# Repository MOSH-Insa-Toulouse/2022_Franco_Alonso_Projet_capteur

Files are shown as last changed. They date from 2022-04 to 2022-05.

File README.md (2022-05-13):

# 2022_Franco_Alonso_Projet_capteur

Ce repository Git contient les ressources nécessaire pour le projet 2022 qui s'inscrit dans l'UF *"Du capteur au banc de Test"* de l'INSA de Toulouse, 4ème année de Génie Physique.

---
## Sommaire

- [2022_Franco_Alonso_Projet_capteur](#2022_franco_alonso_projet_capteur)
  - [Sommaire](#sommaire)
  - [1) Livrables](#1-livrables)
  - [2) Description](#2-description)
  - [3) Shield PCB](#3-shield-pcb)
  - [4) Arduino](#4-arduino)
  - [5) Application Android APK](#5-application-android-apk)
    - [5.1) MIT App inventor](#51-mit-app-inventor)
    - [5.2) Notre application](#52-notre-application)
  - [6) Banc de test](#6-banc-de-test)
    - [6.1) Rayon de courbure](#61-rayon-de-courbure)
    - [6.2) Répétabilité](#62-répétabilité)
  - [7) Datasheet](#7-datasheet)
  - [8) Information sur les auteurs](#8-information-sur-les-auteurs)

---
## 1) Livrables

- Shield PCB réalisé avec KiCad
- Code Arduino permettant la mesure de la resistance et de la tension du capteur, ainsi que le contrôle d'un module Bluetooth, d'un écran OLED et d'un encodeur rotatoire
- Application android APK réalisée avec MIT APP INVENTOR
- Protocole et code Arduino du Banc de test
- Datasheet du capteur de déformation

---
## 2) Description

Dans le cadre de l'UF MOSH, nous avons conçu un capteur résistif composé de matériaux peu chers : un simple papier et un crayon suffisent à créer ce capteur.

Ici, le phénomène physique observé est l'effet tunnel. En effet, il existe un lien entre la conduction des électrons et la distance interatomique du réseau percolet. En faisant varier la distance séparant les particules du réseau (en pliant une feuille de papier sur laquelle on aura déposé du graphite par exemple), la conductivité du graphite varie, la résistivité varie également, et donc, la résistance variera aussi en fonction des dimensions du capteur. C'est cette propriété que l'on va exploiter afin de créer notre capteur résistif.  

Nous avons également implémenté  un shield sur notre chaine de mesures. Ce dernier a été conçu a l'aide du logiciel KICAD et aura un rôle de conditionneur du signal. Le shield est composé d'un amplificateur transimpédance, d'un module Bluetooth, d'un écran OLED, d'un encodeur rotatoire ainsi que d'une entrée analogique pour le capteur résistif.  

Pour finir, nous avons effectué l'ensemble des tests du circuit sur le logiciel LTSpice (voir [_Rapport LTSpice_](https://github.com/MOSH-Insa-Toulouse/2022_Franco_Alonso_Projet_capteur/blob/8504636d878c9423babecade3b70e7a892836c6b/Rapport_LTSpice.pdf)).  

Nous avons ensuite imprimé notre circuit PCB après validation de l'équipe pédagogique.  

Puis, nous avons utilisé une carte Arduino pour la lecture des mesures et la création des fonctions relatives à l'écran OLED, au module Bluetooth ainsi qu'a l'encodeur rotatoire.  

Ensuite, avec le site MIT App Inventor, nous avons développé une application Android qui a pour but de recevoir des données via Bluetooth.  

Et enfin, nous avons réalisé notre propre banc de test : nous avons effectué un test de rayon de courbure et un test de répétabilité avec deux types de crayons (B, HB).  

---
## 3) Shield PCB

Sur le logiciel KICAD nous avons créé des modèles pour l'amplificateur transimpédance, le module Bluetooth, l'écran OLED et l'encodeur rotatoire. Nous avons ensuite créé ou assigné des empreintes à chaque composante du circuit électronique (amplificateur, Bluetooth, OLED, encodeur rotatoire mais aussi résitances et capacités). Puis, nous avons tracé le chevelu du PCB et enfin nous avons modélisé notre PCB en 3D pour vérifier qu'aucun élément ne se superpose et qu'il n'y aura pas de problème lors de la réalisation du PCB.  

Schéma du circuit électrique sur LTSpice:  
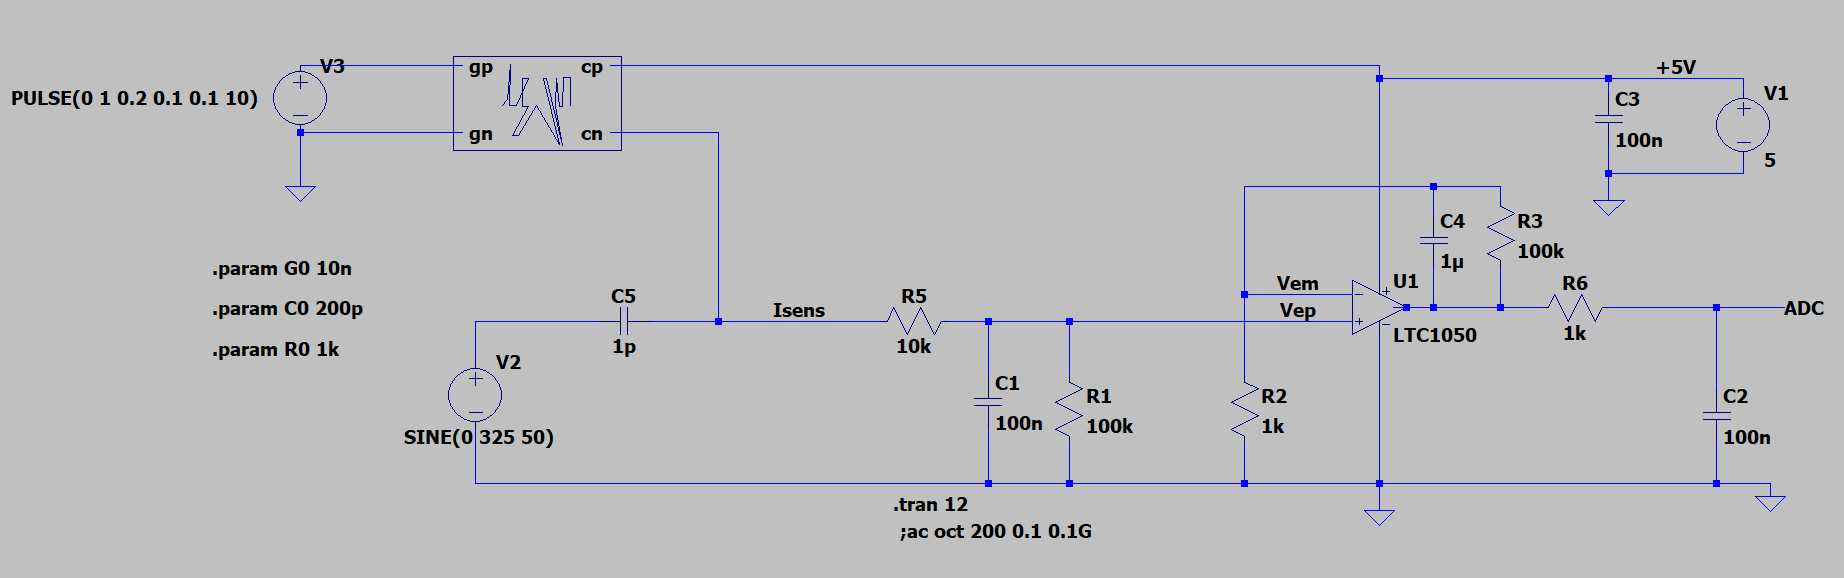
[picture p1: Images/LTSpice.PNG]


Schématique de l'amplificateur opérationel LTC1050:  
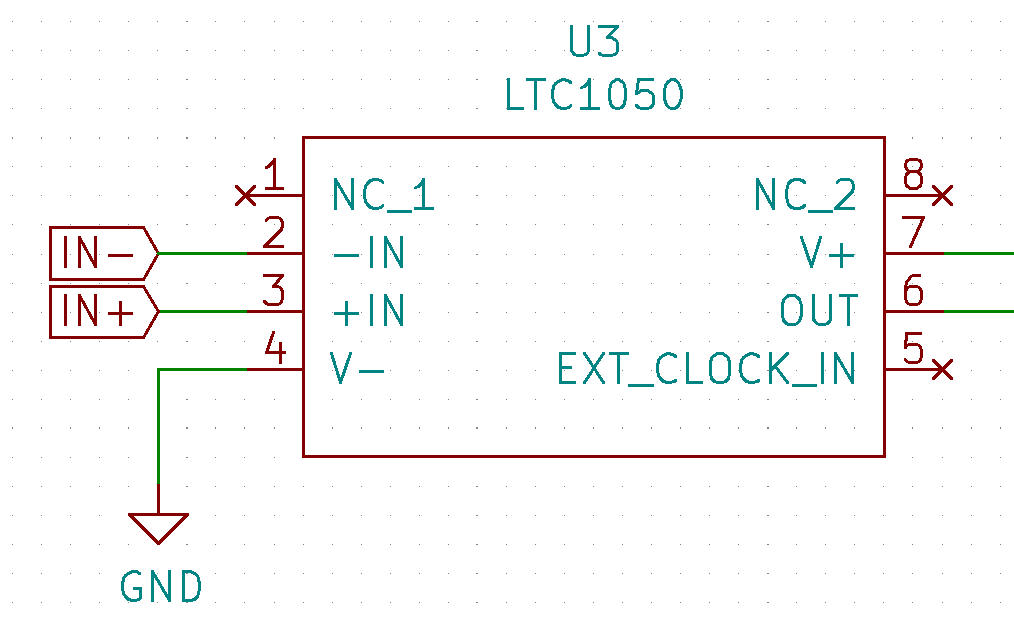
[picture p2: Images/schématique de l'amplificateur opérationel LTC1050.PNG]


Schématique du module Bluetooth HC-05:  
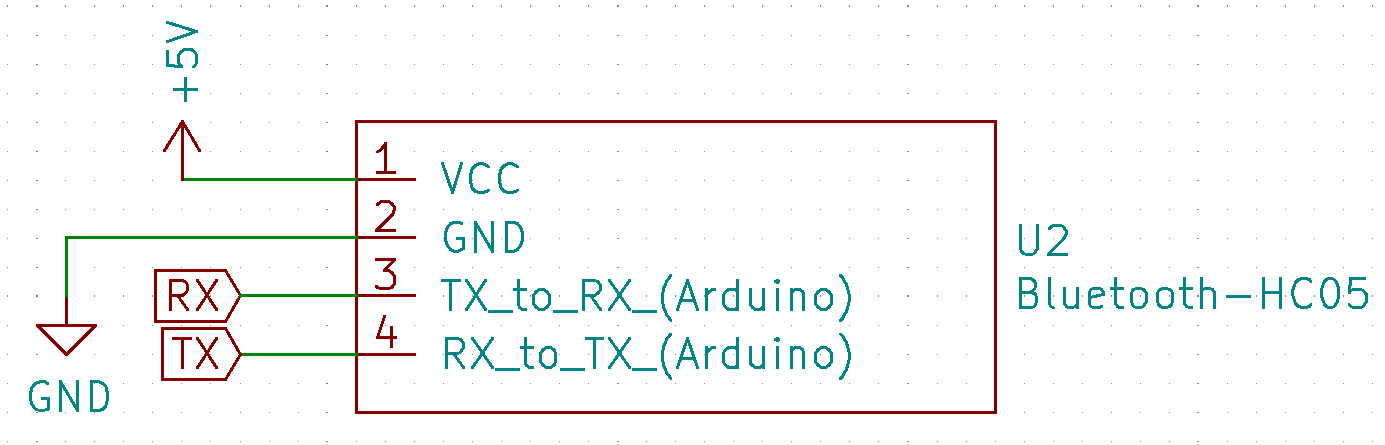
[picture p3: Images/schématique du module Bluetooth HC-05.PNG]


Schématique de l'écran OLED:  
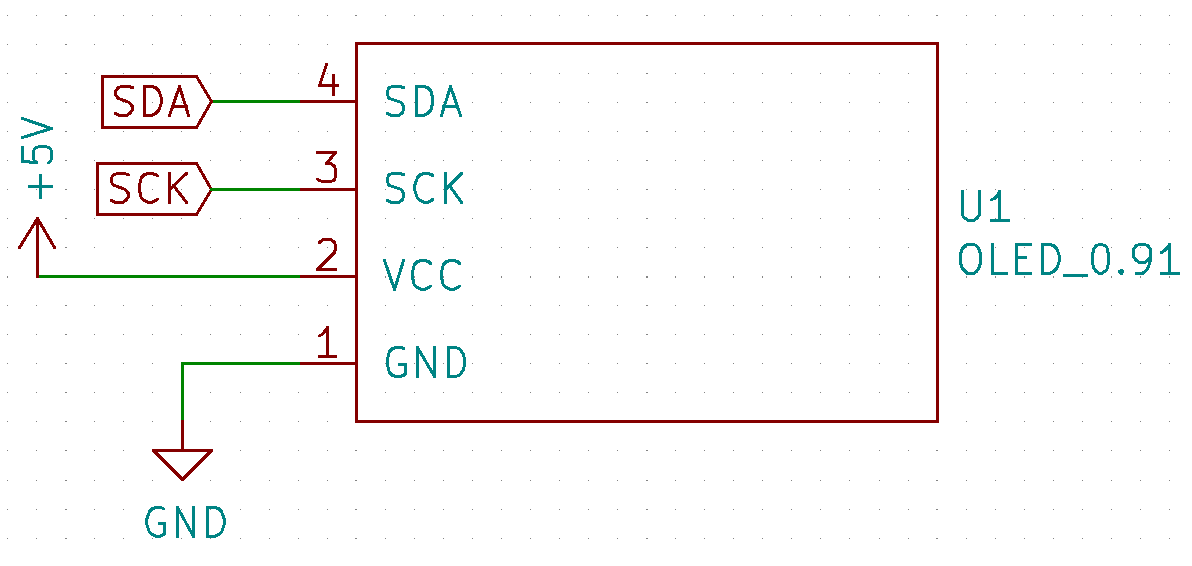
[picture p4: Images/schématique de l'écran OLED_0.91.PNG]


Schématique de l'encodeur rotatoire KY-040:  
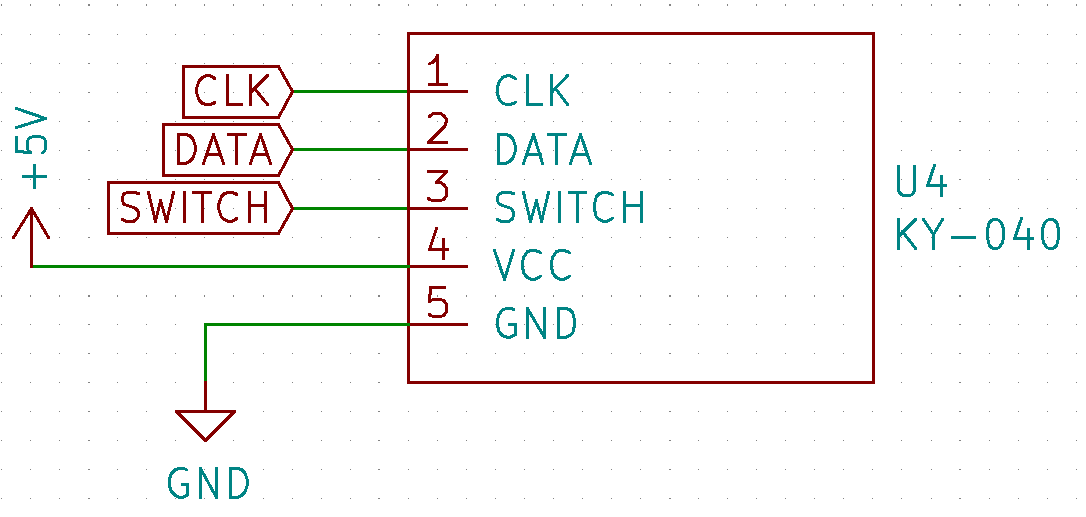
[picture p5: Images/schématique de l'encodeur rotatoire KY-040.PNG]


Schématique des pins de la carte Arduino:  
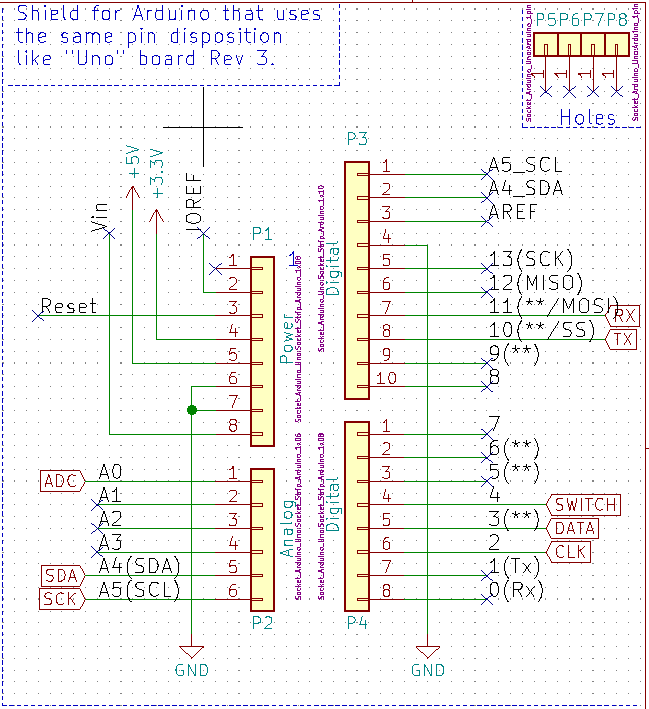
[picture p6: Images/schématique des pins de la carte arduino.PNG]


Schématique du circuit amplificateur transimpédance:  
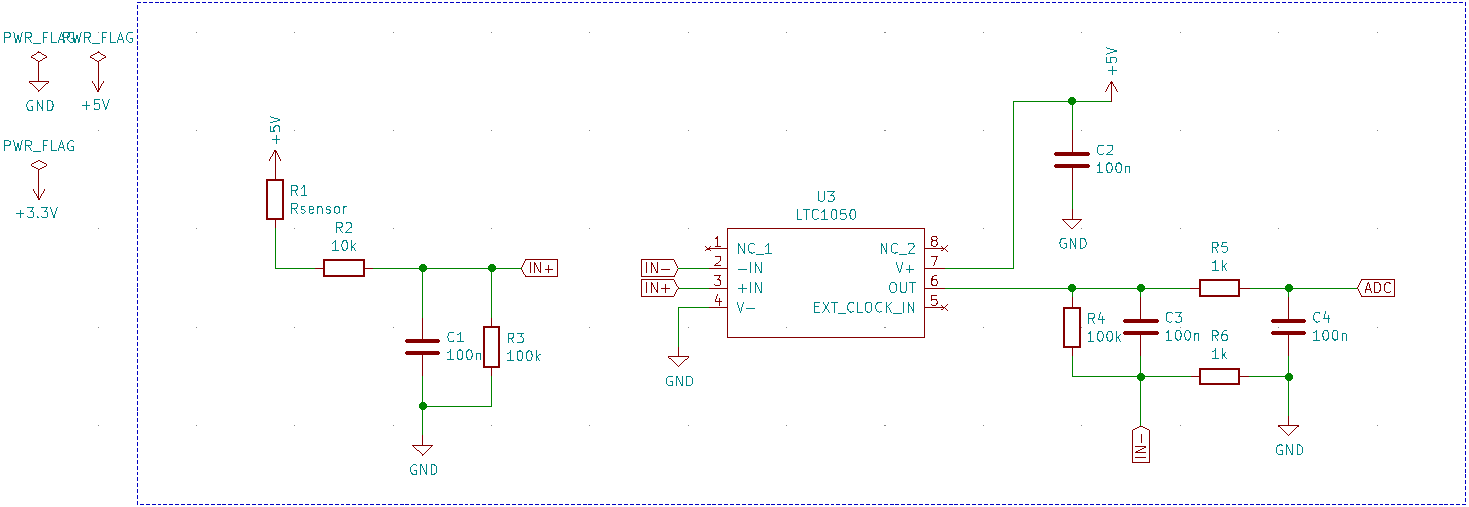
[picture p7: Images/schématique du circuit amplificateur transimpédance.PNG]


Empreinte de l'amplificateur opérationel LTC1050:  
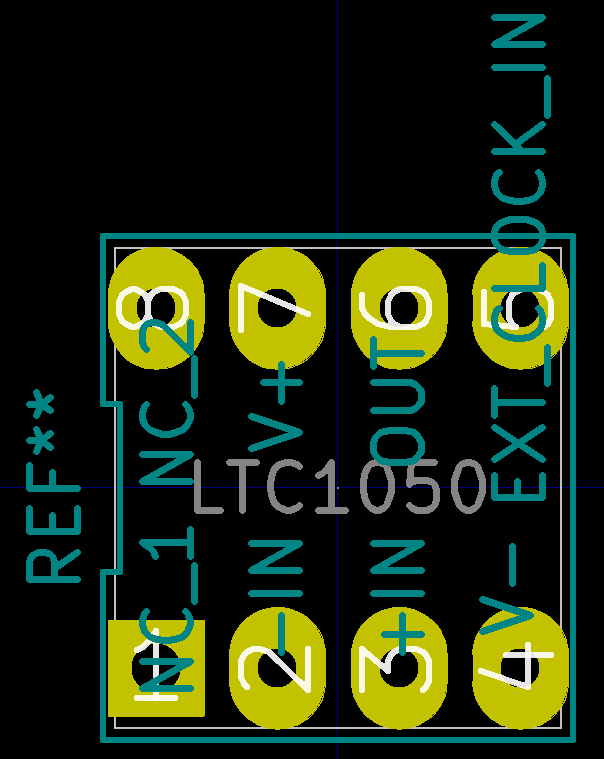
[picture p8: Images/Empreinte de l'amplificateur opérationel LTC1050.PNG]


Empreinte du module Bluetooth HC-05:  
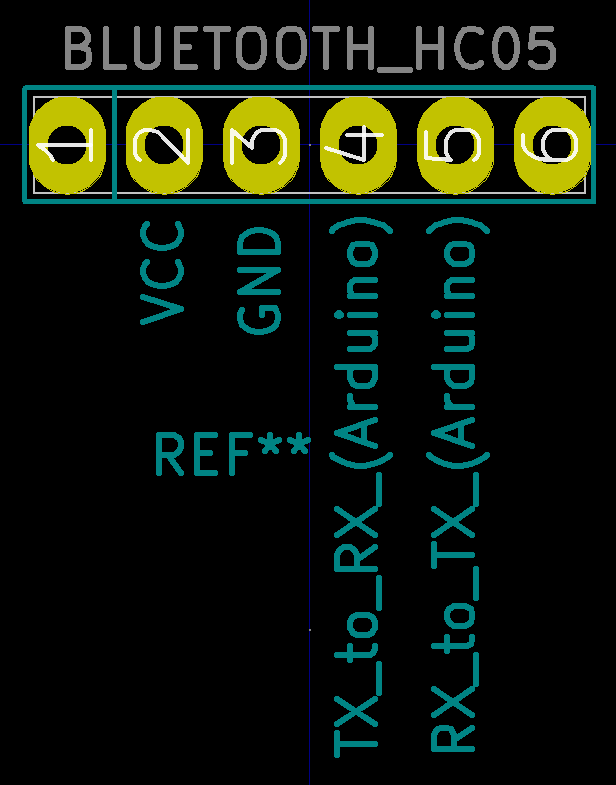
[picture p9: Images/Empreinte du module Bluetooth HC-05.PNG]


Empreinte de l'écran OLED:  
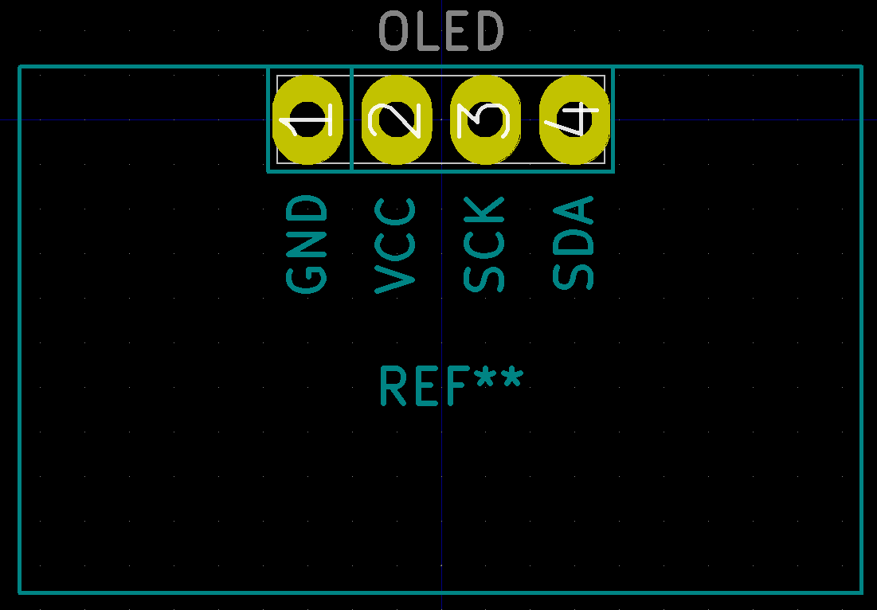
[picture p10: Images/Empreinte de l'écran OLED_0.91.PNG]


Empreinte de l'encodeur rotatoir KY-040:  
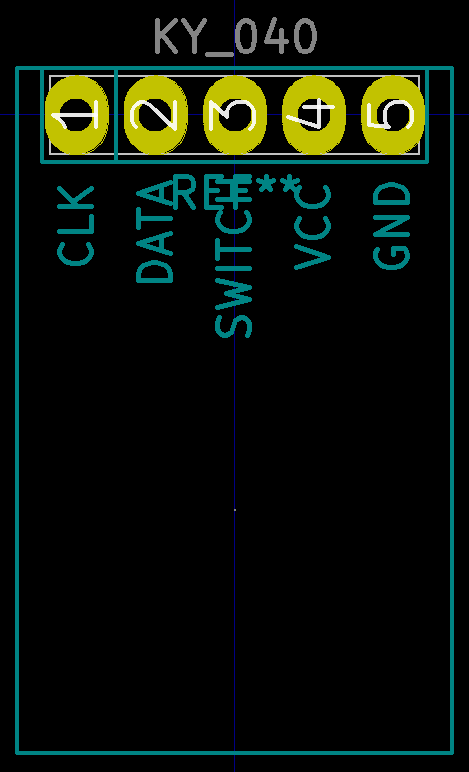
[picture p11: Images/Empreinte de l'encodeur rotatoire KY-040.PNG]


Empreinte du PCB en entier:  
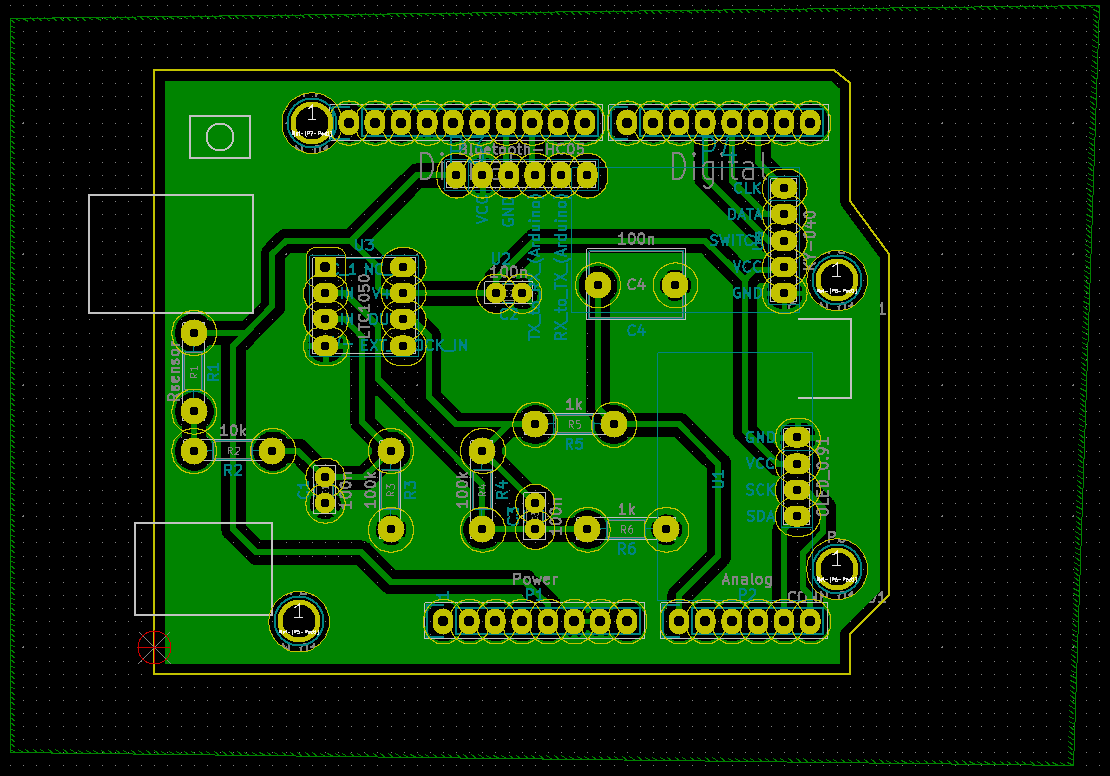
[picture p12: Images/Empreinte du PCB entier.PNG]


Modélisation 3D du PCB:  
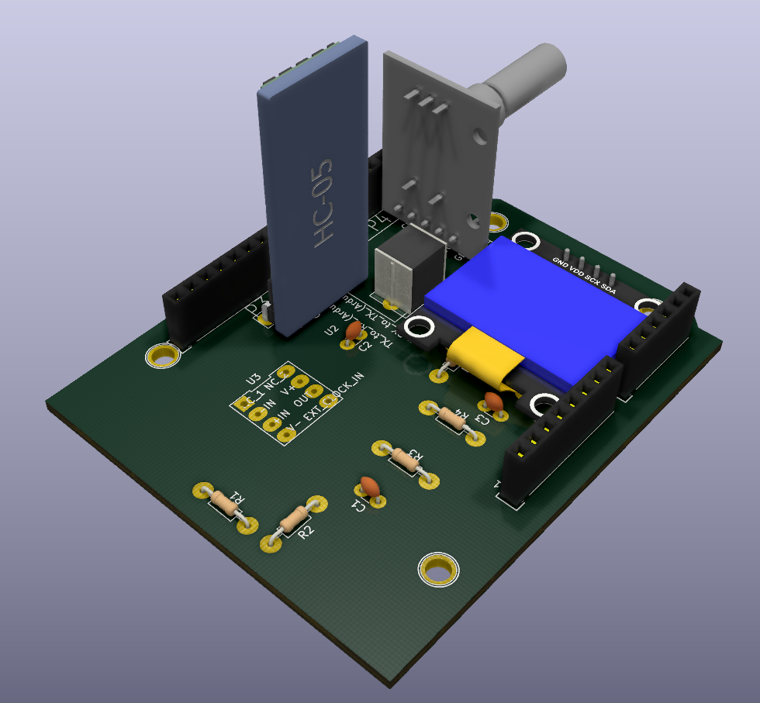
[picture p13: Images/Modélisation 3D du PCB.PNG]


---
## 4) Arduino

Voici notre code Arduino qui permet de :

- mesurer la tension en sortie du circuit transimpédance
- calculer la résistance correspondante du capteur grâce à la tension mesurée (fonction de transfert)
- visualiser ces valeurs (tension et résistance) dans le moniteur série
- afficher ces deux valeurs (tension et résistance) sur l'écran OLED
- envoyer les valeurs de résistance par Bluetooth à l'application APK
- utiliser un encodeur rotatoire pour choisir d'afficher sur l'écran OLED et d'envoyer par Bluetooth les valeurs de résistance en Ω, kΩ ou MΩ  

```
// Pour le Bluetooth
#include <SoftwareSerial.h>
#include <Arduino.h>
#include <string.h>
#define rxPin 11 //Broche 11 en tant que RX, à raccorder sur TX du HC-05
#define txPin 10 //Broche 10 en tant que TX, à raccorder sur RX du HC-05
#define baudrate 9600
#define encoder0PinA  2  //CLK Output A Do not use other pin for clock as we are using interrupt
#define encoder0PinB  3  //DT Output B
#define Switch 5 // Switch connection if available
int value;
int rotation;
int RotPosition = 0;
boolean LeftRight;
float Rs2=0;
volatile unsigned int encoder0Pos = 0;
SoftwareSerial mySerial(rxPin ,txPin); //Définition du software serial

float Vadc;

// Pour le OLED
#include <Adafruit_SSD1306.h>

#define nombreDePixelsEnLargeur 128         // Taille de l'écran OLED, en pixel, au niveau de sa largeur
#define nombreDePixelsEnHauteur 64          // Taille de l'écran OLED, en pixel, au niveau de sa hauteur
#define brocheResetOLED         -1          // Reset de l'OLED partagé avec l'Arduino (d'où la valeur à -1, et non un numéro de pin)
#define adresseI2CecranOLED     0x3C        // Adresse de "mon" écran OLED sur le bus i2c (généralement égal à 0x3C ou 0x3D)

Adafruit_SSD1306 ecranOLED(nombreDePixelsEnLargeur, nombreDePixelsEnHauteur, &Wire, brocheResetOLED);

/////////////////////////////////////////////////////////////////////////////////////////////////////////////////////////////////////////////////////////////////////////

void Affichage_OLED(float Rs, float Vadc){ 
  byte tailleDeCaractere=2;
  byte numeroDeLigne=1;
  boolean bCouleurInverse = false;
  ecranOLED.clearDisplay();                                   // Effaçage de l'intégralité du buffer
  ecranOLED.setTextSize(tailleDeCaractere);                   // Taille des caractères (1:1, puis 2:1, puis 3:1)
  ecranOLED.setCursor(0, 0);                                  // Déplacement du curseur en position (0,0), c'est à dire dans l'angle supérieur gauche
  ecranOLED.setTextColor(SSD1306_WHITE);                  // Affichage du texte en "blanc" (avec la couleur principale, en fait, car l'écran monochrome peut être coloré)
  ecranOLED.print("V= ");
  ecranOLED.print(Vadc);
  ecranOLED.println(" V");
  ecranOLED.print("R= ");
  ecranOLED.print(Rs);
  bCouleurInverse = !bCouleurInverse;
  ecranOLED.display();                            // Transfert le buffer à l'écran

  // ***********************************************************************
  // Affichage de 8 lignes à couleurs alternées, dans chaque écran successif
  // ***********************************************************************
  
  /*if(bCouleurInverse)
    ecranOLED.setTextColor(SSD1306_BLACK, SSD1306_WHITE);   // Couleur du texte, et couleur du fond
  else
    
  delay(500);*/
}

/////////////////////////////////////////////////////////////////////////////////////////////////////////////////////////////////////////////////////////////////////////

double Rs;
int Vcc=5;
int R1=100000;
int R3=100000;
int R5=10000;
int R2=1000;

void Bluetooth_write(double Rs){
  double Res = Rs;
  mySerial.println(Res);
  delay(500);
}

/////////////////////////////////////////////////////////////////////////////////////////////////////////////////////////////////////////////////////////////////////////

void mesure(){
  // read the input on analog pin 0:
  double  sensorValue = analogRead(A0);         //on divise par 4 pour être sur une plage de 256 et non une plage de 1024 car l'analogRead donne une valeur entre 0 et 1023
  
  // Convert the analog reading (which goes from 0 - 1023) to a voltage (0 - 5V):
  Vadc = sensorValue * (Vcc / 1023.0);
 
  Rs = ((1+R3/R2)*R1*(1023/Vadc))-R1-R5;
  //Serial.println(Vadc); 
}

// on voit sur le moniteur que Rs varie entre 35000 et 15M environ

/////////////////////////////////////////////////////////////////////////////////////////////////////////////////////////////////////////////////////////////////////////

void setup() {
  Serial.begin(9600);
  pinMode(rxPin,INPUT);
  pinMode(txPin,OUTPUT);
  mySerial.begin(9600);
  ecranOLED.begin(SSD1306_SWITCHCAPVCC, adresseI2CecranOLED);
  pinMode(encoder0PinA, INPUT); 
  digitalWrite(encoder0PinA, HIGH);       // turn on pullup resistor
  pinMode(encoder0PinB, INPUT); 
  digitalWrite(encoder0PinB, HIGH);       // turn on pullup resistor
  rotation = digitalRead(encoder0PinA); 
}

void loop() {
 value = digitalRead(encoder0PinA);
     if (value != rotation){ // we use the DT pin to find out which way we are turning.
     if (digitalRead(encoder0PinB) != value) {  // Clockwise
       RotPosition ++; 
       if (RotPosition==3){
        RotPosition=0;
       }
     } else { //Counterclockwise
       RotPosition--;
       if (RotPosition==-3){
        RotPosition=0;
       }
     }
     rotation = value;
     }
    mesure();
      if (RotPosition==-1){
        //mesure();
        Rs=Rs/1000;
        Bluetooth_write(Rs);  
        Affichage_OLED(Rs, Vadc);
        //Serial.println(Rs);
        ecranOLED.println(" k");
        ecranOLED.display();
     }
      else if (RotPosition==-2){
        //mesure();
        //Serial.println(Rs/1000000);
        Bluetooth_write(Rs/1000000);
        Affichage_OLED(Rs/1000000, Vadc);
        ecranOLED.println(" M");
        ecranOLED.display();
     }
     else if (RotPosition==0){
        //Serial.println(Rs);
      Bluetooth_write(Rs);
      Affichage_OLED(Rs, Vadc); 
     }
      else if (RotPosition==1){
        //mesure();
        Rs=Rs/1000;
        Bluetooth_write(Rs);  
        Affichage_OLED(Rs, Vadc);
        //Serial.println(Rs);
        ecranOLED.println(" k");
        ecranOLED.display();
     }
      else if (RotPosition==2){
        //mesure();
       // Serial.println(Rs/1000000);
        Bluetooth_write(Rs/1000000);
        Affichage_OLED(Rs/1000000, Vadc);
        ecranOLED.println(" M");
        ecranOLED.display();
     }
     else{
      //mesure();
      //Serial.println(Rs);
      Bluetooth_write(Rs);
      Affichage_OLED(Rs, Vadc);  
     }
     //Serial.print("Encoder RotPosition: ");
     //Serial.println(RotPosition);
     
     Serial.println(Rs);
     //Serial.println(Vadc);
     // this will print in the serial monitor.  
}
```

---
## 5) Application Android APK

L'application android développée sur MIT App Inventor sert à:

- Récupérer la valeur de la résistance du capteur graphite (calculée par le code Arduino à partir de la tension mesurée)
- Afficher cette valeur de résistance
- Tracer un graphique qui décrit l'évolution de la résistance du capteur en fonction du temps

### 5.1) MIT App inventor

Le site internet de création d'application [_MIT App Inventor_](https://appinventor.mit.edu/)

### 5.2) Notre application

Interface de l'application sur un smartphone :  
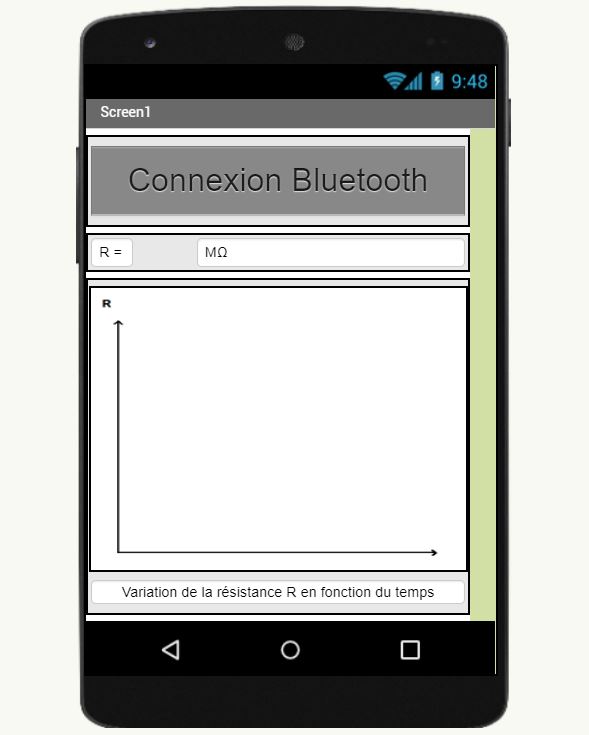
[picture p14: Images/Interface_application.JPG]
  

Schéma en block du code de l'application :  
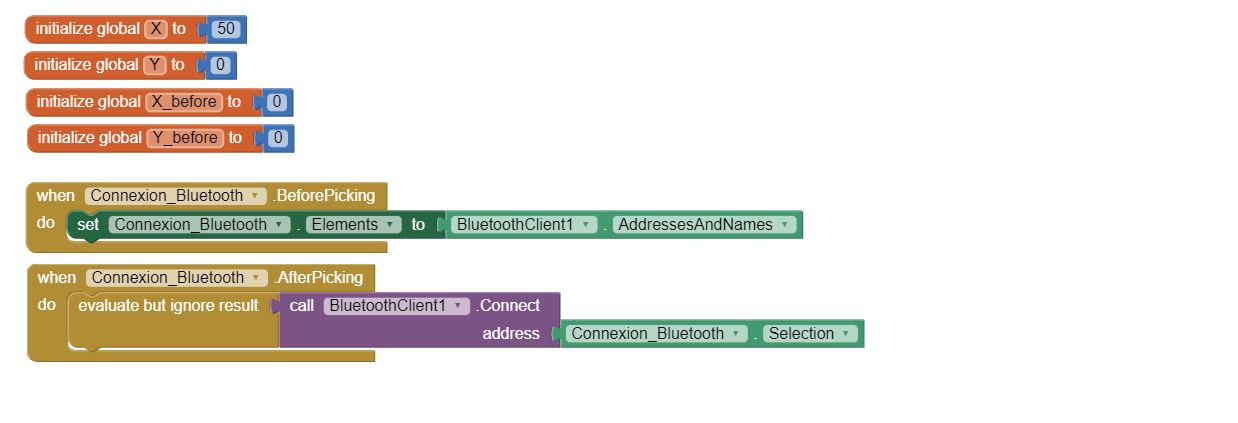
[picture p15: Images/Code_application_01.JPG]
  
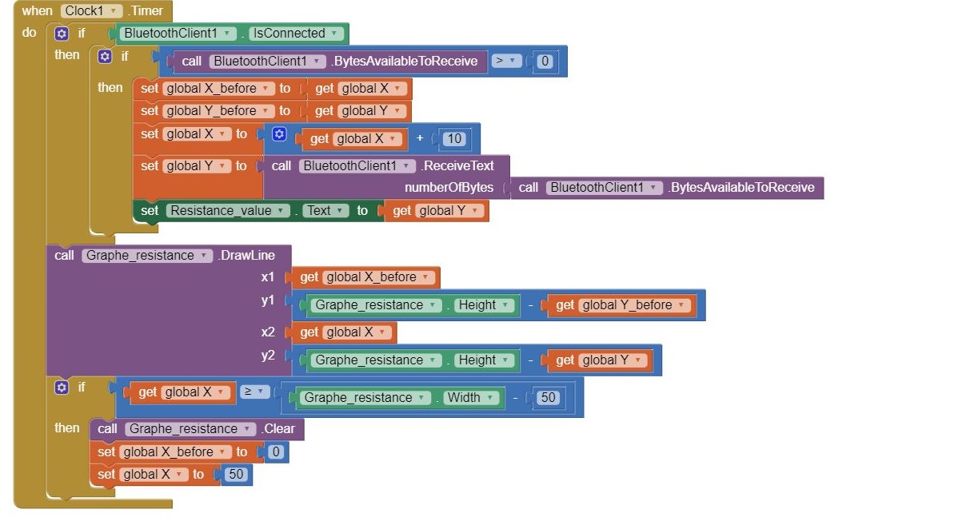
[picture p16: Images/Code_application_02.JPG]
  

Toutefois, notre application est perfectible. Il lui arrive d'avoir des erreurs obligeant l'application à se fermer, notamment lorsque le smartphone reçoit des valeurs infinies.  

---
## 6) Banc de test

### 6.1) Rayon de courbure

Nous avons effectué différents tests pour étudier l'influence du rayon de courbure sur la résistance de notre capteur. Pour cela, nous avons créé un banc de test "low-cost" en prenant différents objets cylindriques présents dans la salle d'instrumentation du Génie Physique (GP).

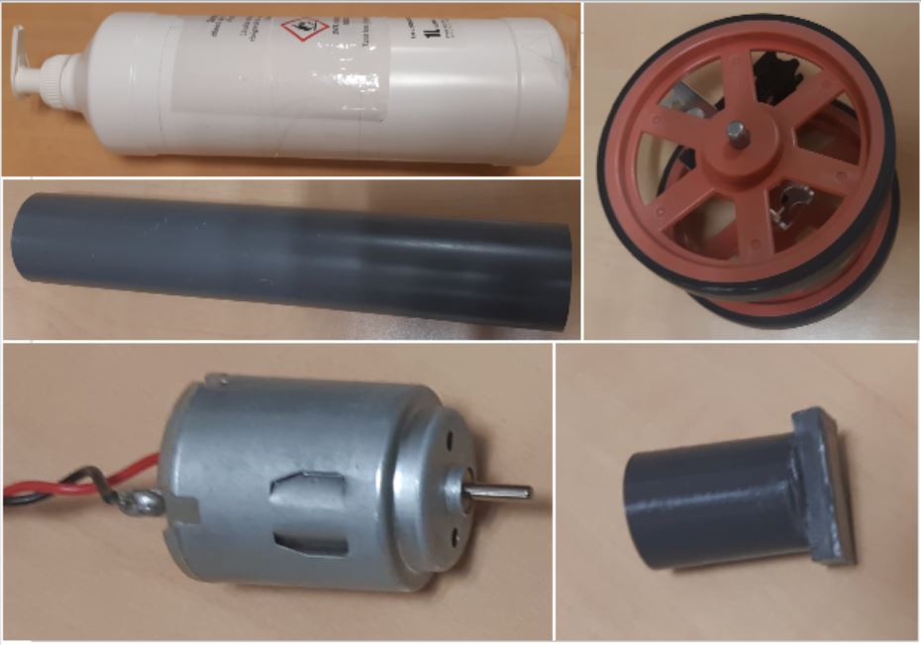
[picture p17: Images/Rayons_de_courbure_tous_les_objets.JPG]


Puis, nous avons enroulé notre capteur autour de ces objets cylindriques dans un sens comme dans l'autre (extension/compression) et mesuré les variations de résistance pour les crayons de type B et de type HB.
Nous avons alors tracé deux graphes avec leurs courbes de tendance:  

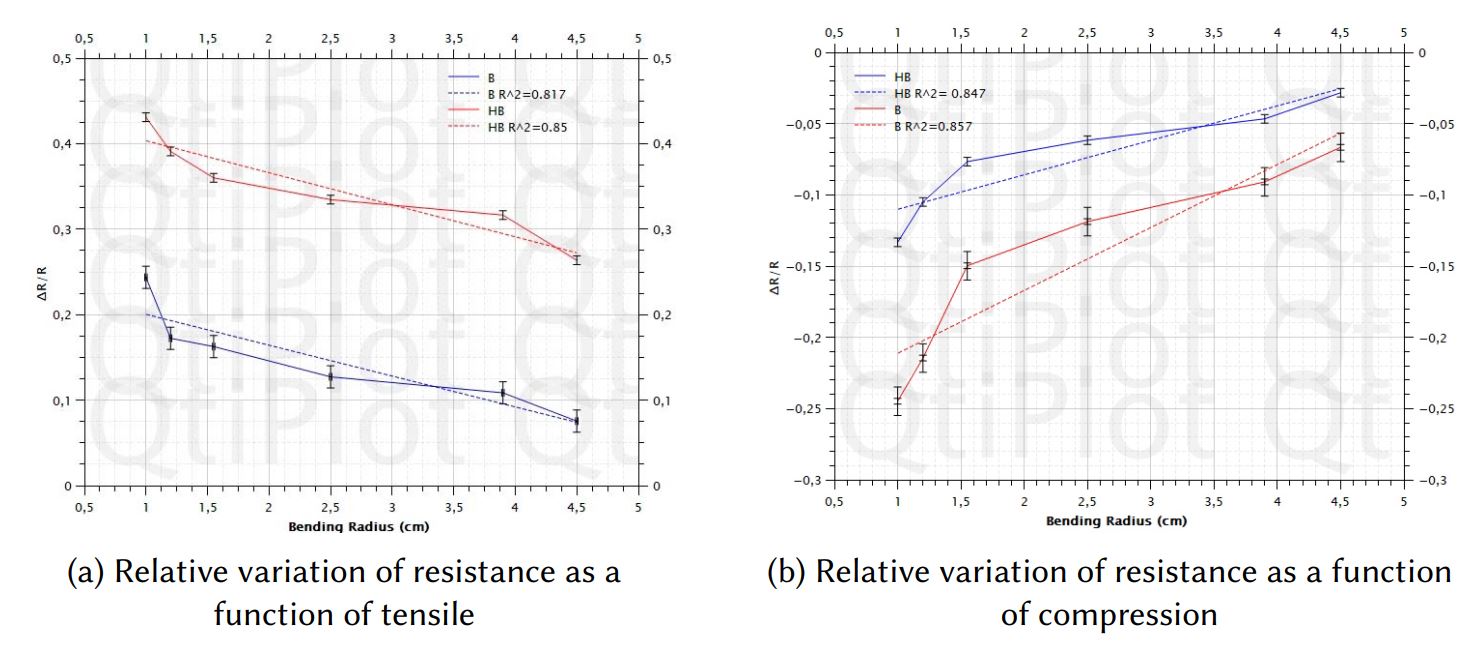
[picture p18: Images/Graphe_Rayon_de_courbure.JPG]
  

### 6.2) Répétabilité

Ici, nous avons voulu mesurer la répétabilité de notre capteur, c'est-à-dire, à partir de combien de mesures notre capteur n'est plus fiable.
Pour y arriver, nous avons créé notre propre banc de test à partir d'un servo-moteur (et son code Arduino), de scotch, de carton et d'un support en rigide. Nous avons agrandi l'aile fixé au servo-moteur grâce à un morceau de carton et nous avons scotché ce servo-moteur à un support rigide que nous avons lui même scotché sur le bord d'un meuble. En ce qui concerne le capteur, nous avons scotché un support rigide sur le bord du même meuble à une petite distance de notre servo-moteur, ce qui nous a permis de positionner les pinces métalliques et notre capteur face à l'aile du servo-moteur qui va effectuer des aller-retours pour que le capteur subisse des cycles d'extension/compression (voir [_Vidéo test de répétabilité_](https://github.com/MOSH-Insa-Toulouse/2022_Franco_Alonso_Projet_capteur/blob/469d8a52910f487a39b89d7652cd1226eb0d3d92/Images/Test_Repetabilite_video.mp4)).  

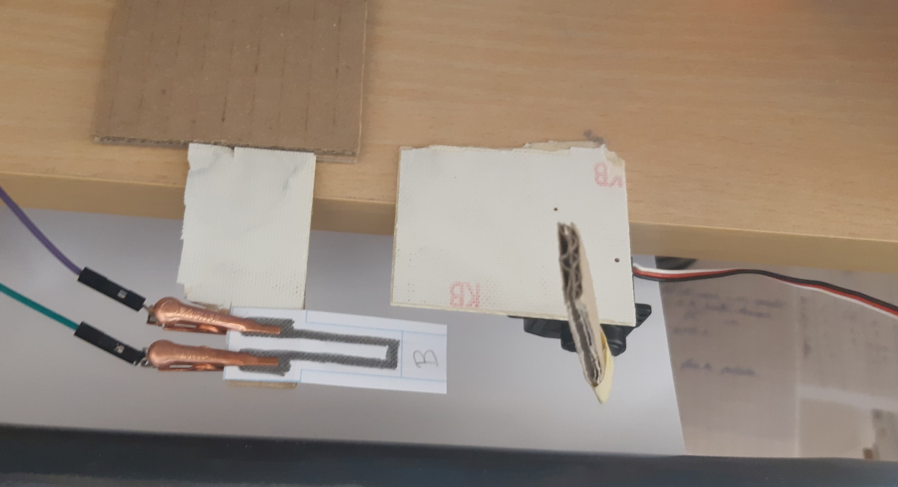
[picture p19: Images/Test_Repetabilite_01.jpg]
  

Après des mesures pour des crayons de type B et des crayons de type HB, nous avons obtenu deux courbes représentant l'évolution de la résistance mesurée par le capteur en fonction du nombre de cyles d'extension/compression effectués.  

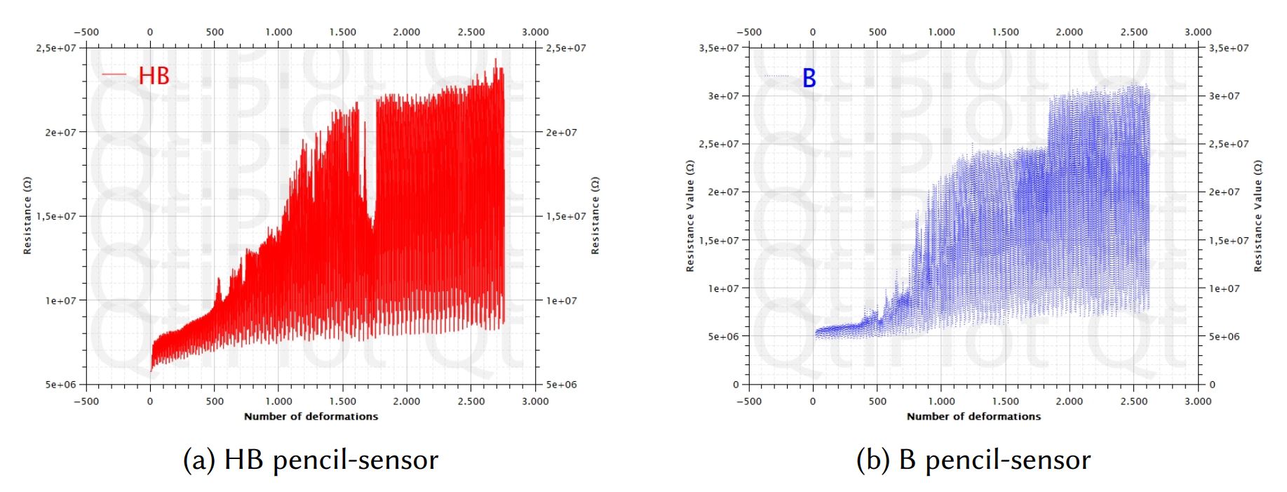
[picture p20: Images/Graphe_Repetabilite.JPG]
  

Code Arduino du servo-moteur:  

```
// Sweep by BARRAGAN
#include <Servo.h>

Servo myservo;  // create servo object to control a servo
                // a maximum of eight servo objects can be created

int pos = 0;    // variable to store the servo position

void setup()
{
  Serial.begin(9600);
  myservo.attach(9);  // attaches the servo on pin 9 to the servo object
}

void loop()
{
  for(pos = 30; pos <= 150; pos += 1)  // goes from 30 degrees to 150 degrees
  {                                  // in steps of 1 degree
    myservo.write(pos);              // tell servo to go to position in variable 'pos'
    Serial.println(pos);
    delay(5);                       // waits 5ms for the servo to reach the position
  }
  for(pos = 150; pos>=31; pos-=1)     // goes from 150 degrees to 30 degrees
  {                                
    myservo.write(pos);              // tell servo to go to position in variable 'pos'
    Serial.println(pos);
    delay(5);                       // waits 5ms for the servo to reach the position
  }
} 
```

---
## 7) Datasheet

Datasheet en format pdf à télécharger [_ici_](https://github.com/MOSH-Insa-Toulouse/2022_Franco_Alonso_Projet_capteur/blob/540ff39c7f5d5399cfc770728529d42a2bad8d82/Datasheet/Datasheet_Capteur_papier.pdf).

---
## 8) Information sur les auteurs

Edouard FRANCO / Pablo ALONSO RODRIGUEZ

- edouard.franco@free.fr
- pablo.alonsorgz@gmail.com

Étudiants à l'INSA de Toulouse en 4ème année Génie Physique

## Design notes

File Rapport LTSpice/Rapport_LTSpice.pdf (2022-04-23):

# Du capteur au banc de test: Analyse électrique (LTSpice)

### Pablo Alonso Rodríguez Edouard Franco

### 14 avril 2022

## Introduction

Dans le cadre de l’UF "Du capteur au banc de test", nous avons développé un capteur papier capable de mesurer la variation de résistance électrique qu’offre le graphite en fonction de la contrainte mécanique à laquelle il est soumis.

Pour cela, plusieurs étapes de design ont été réalisées, comme la conception du circuit électrique qui permet de faire les mesures pertinentes. Grâce au logiciel LTSpice, la construction et le test d’un circuit théorique ont été possibles, ce qui nous a permis de récupérer beaucoup d’information qui a été nécessaire lors de la mise en place expérimentale du capteur.

## I Circuit Electrique

Le circuit électrique a été construit en 3 différentes parties (Figure 1). La première, entourée en vert, correspond à une source fictive de bruit que nous avons modélisé comme un générateur de tension sinusoïdale de fréquence 50 Hz en série avec une capacité de 1 pF (qui nous permet d’avoir des fluctuations).

La deuxième, encadrée en rouge, c’est le circuit qui va nous permettre d’éliminer le bruit du signal délivré par le capteur et l’amplifier pour une bonne lecture. On peut voir dans l’entrée non-inverseuse de l’amplificateur opérationnel LT1050 un filtre passe bas grâce à l’emplacement de C1 et R5. De plus, il y a un filtre actif passe-bas et en sortie, on a une tension VADC qui va nous permettre de connaître à chaque moment la résistance du capteur (RS).

Finalement, la partie entourée en bleu, qui correspond à la modélisation théorique du capteur, qui est alimenté par un générateur de tension continue de 5V (alimentation fournie par la plaque Arduino Uno). Le capteur, (boite rectangulaire avec motif dessiné), est aussi connecté à une générateur PULSE, qui simule les différentes déformations subies par le capteur.

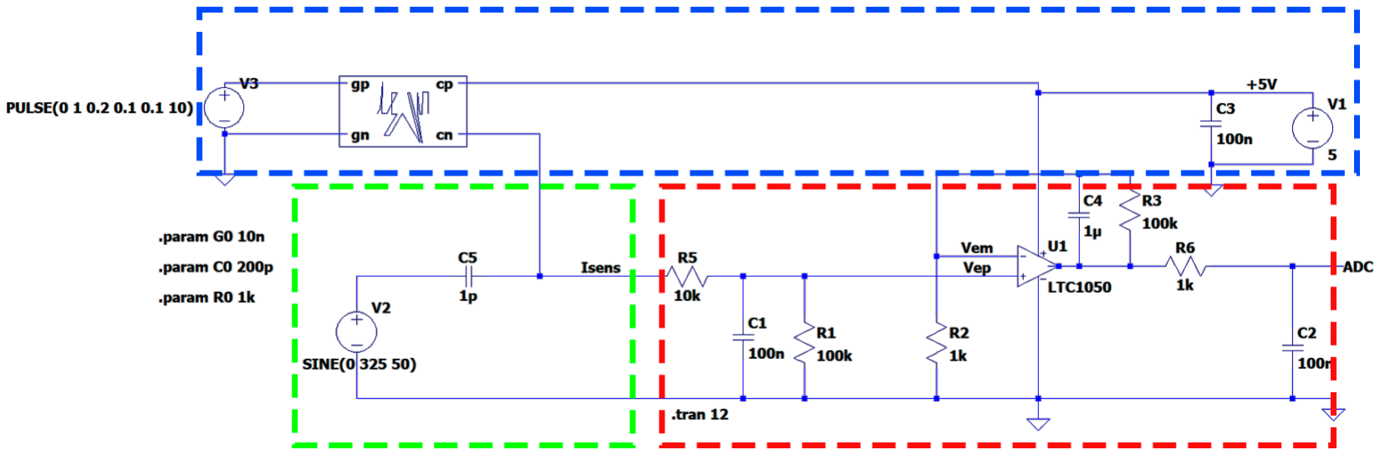
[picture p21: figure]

Figure 1 – Schéma du circuit électrique

II | Simulations électriques
II.1 | Circuit théorique

Dans le but d’étudier le circuit théorique, nous avons déconnecté la source de bruit fictive et nous avons lancé une simulation transiante (Figure 2a) et une fréquentielle (Figure 2b) pour vérifier le signal de sortie. Le comportement du signal de sortie est l’attendu.

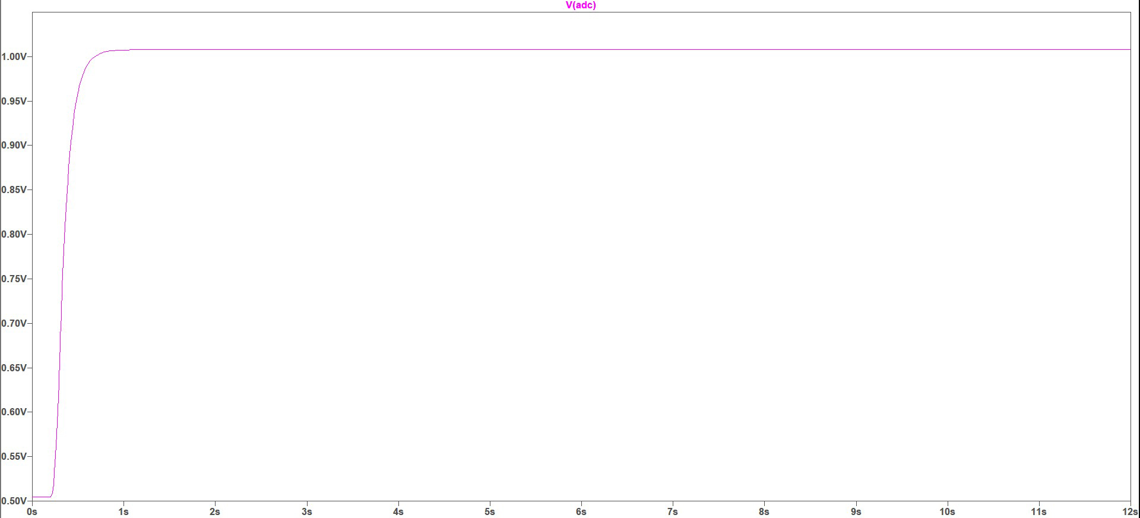
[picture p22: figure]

(a) Simulation transiante

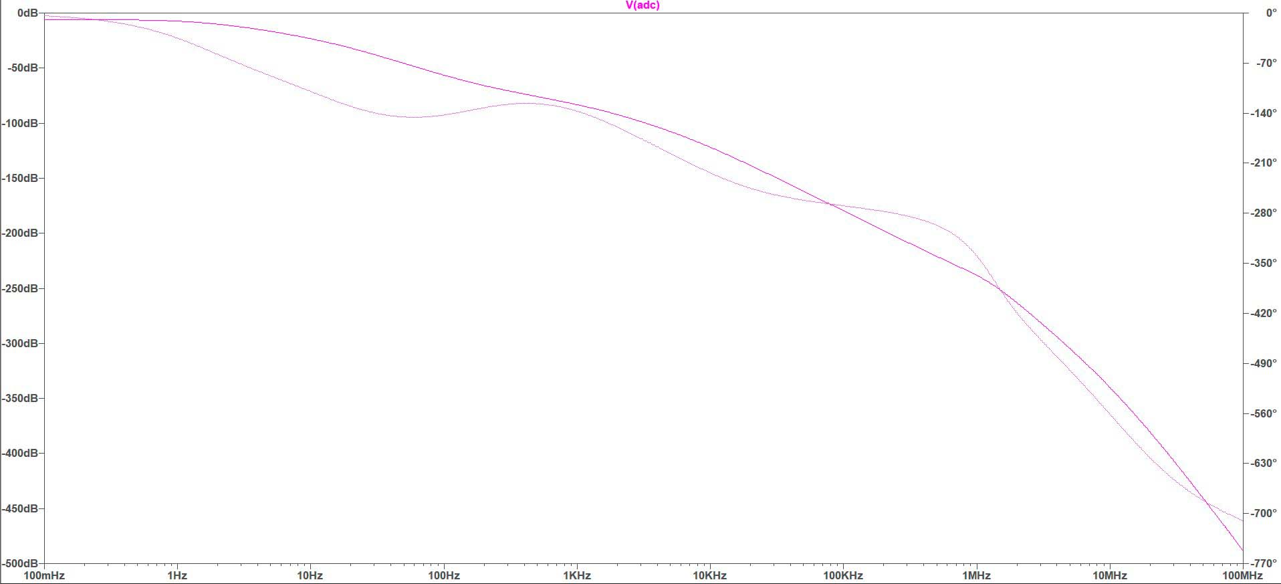
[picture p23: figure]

(b) Simulation fréquentielle

Figure 2 – Simulation du circuit théorique

### II.2 Circuit bruité

Dans cette deuxième partie des simulations, nous avons activé le générateur sinusoïdal pour étudier l’action des 3 filtres présents dans le circuit. Pour cela, nous avons éliminé à tour de rôle

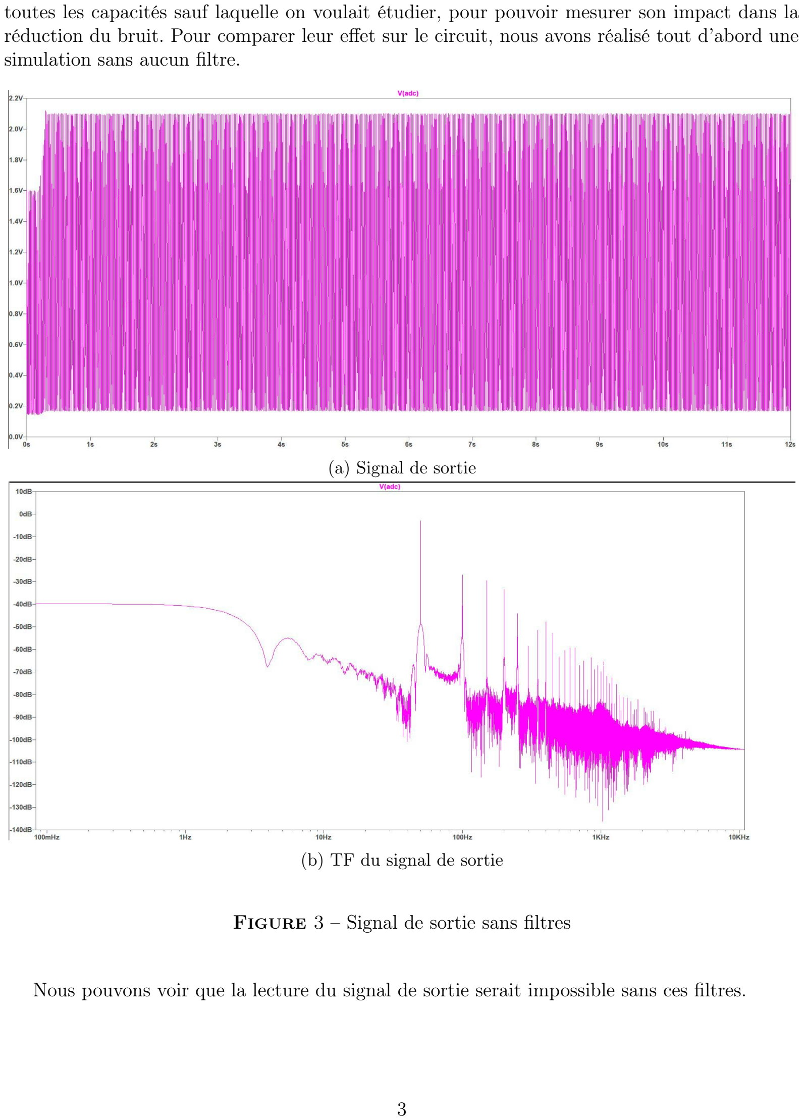
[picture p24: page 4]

toutes les capacités sauf laquelle on voulait étudier, pour pouvoir mesurer son impact dans la réduction du bruit. Pour comparer leur effet sur le circuit, nous avons réalisé tout d’abord une simulation sans aucun filtre.

(a) Signal de sortie
(b) TF du signal de sortie

Figure 3 – Signal de sortie sans filtres

Nous pouvons voir que la lecture du signal de sortie serait impossible sans ces filtres.

II.2.1 Filtre passe-bas R5-C1

Si on ne garde que ce premier filtre actif, nous pouvons voir dans la Figure 4 que le signal est très bruité et à peine illisible. De plus, grâce à une transformée de Fourier, nous pouvons voir que le bruit à 50 Hz présent dans le circuit reste très important, l’atténuation n’est que de 10 dB. Par contre, le filtre élimine une grande partie du bruit au dessus de 100Hz, ce qui est normal, étant donné que sa fréquence de coupure est de 160 Hz, car

fc =

1
2πRC

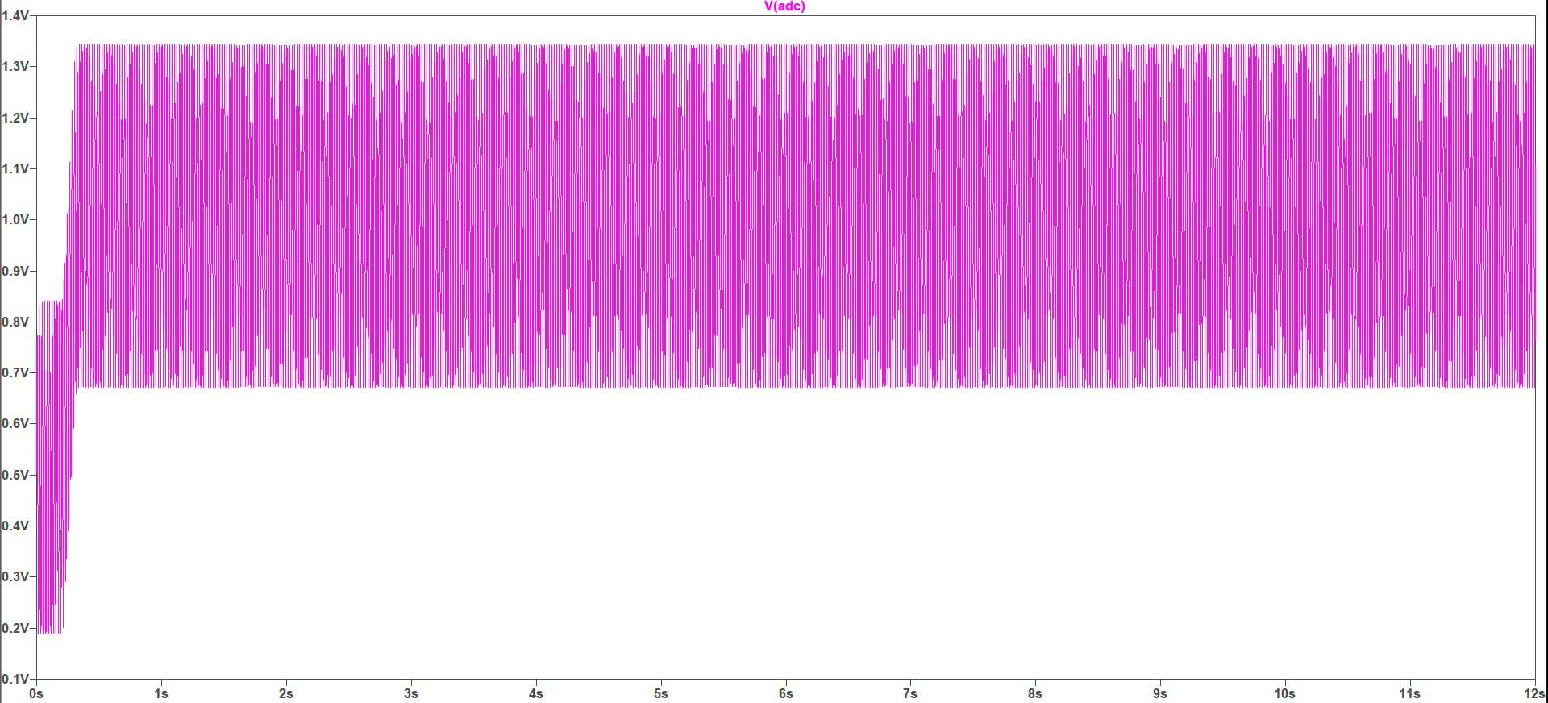
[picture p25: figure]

(a) Signal de sortie

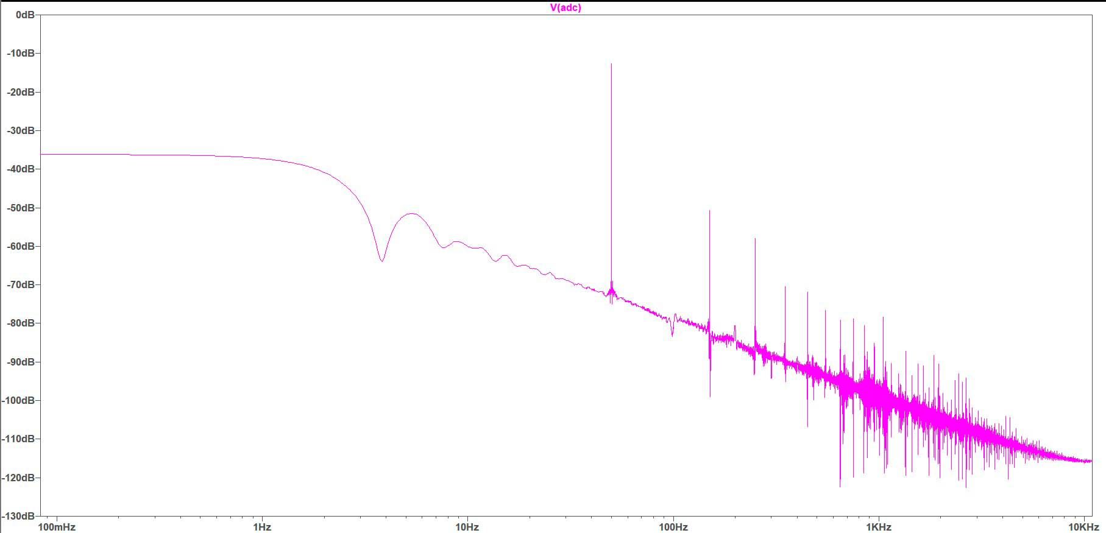
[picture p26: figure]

(b) TF du signal de sortie

Figure 4 – Signal de sortie avec seulement le premier filtre

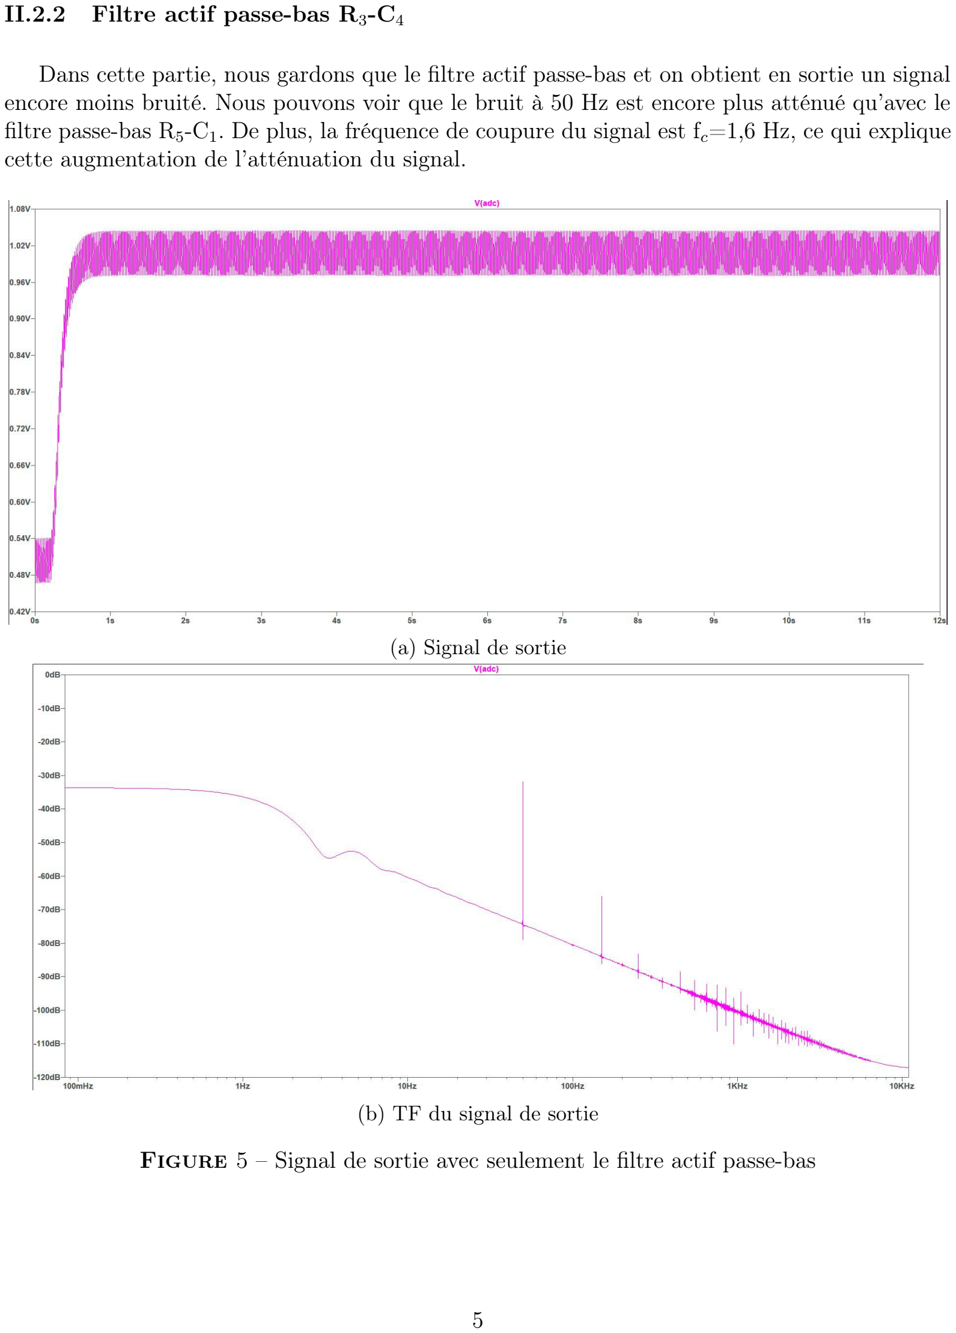
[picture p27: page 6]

II.2.2 Filtre actif passe-bas R3-C4

Dans cette partie, nous gardons que le filtre actif passe-bas et on obtient en sortie un signal encore moins bruité. Nous pouvons voir que le bruit à 50 Hz est encore plus atténué qu’avec le filtre passe-bas R5-C1. De plus, la fréquence de coupure du signal est fc=1,6 Hz, ce qui explique cette augmentation de l’atténuation du signal.

(a) Signal de sortie
(b) TF du signal de sortie

Figure 5 – Signal de sortie avec seulement le filtre actif passe-bas

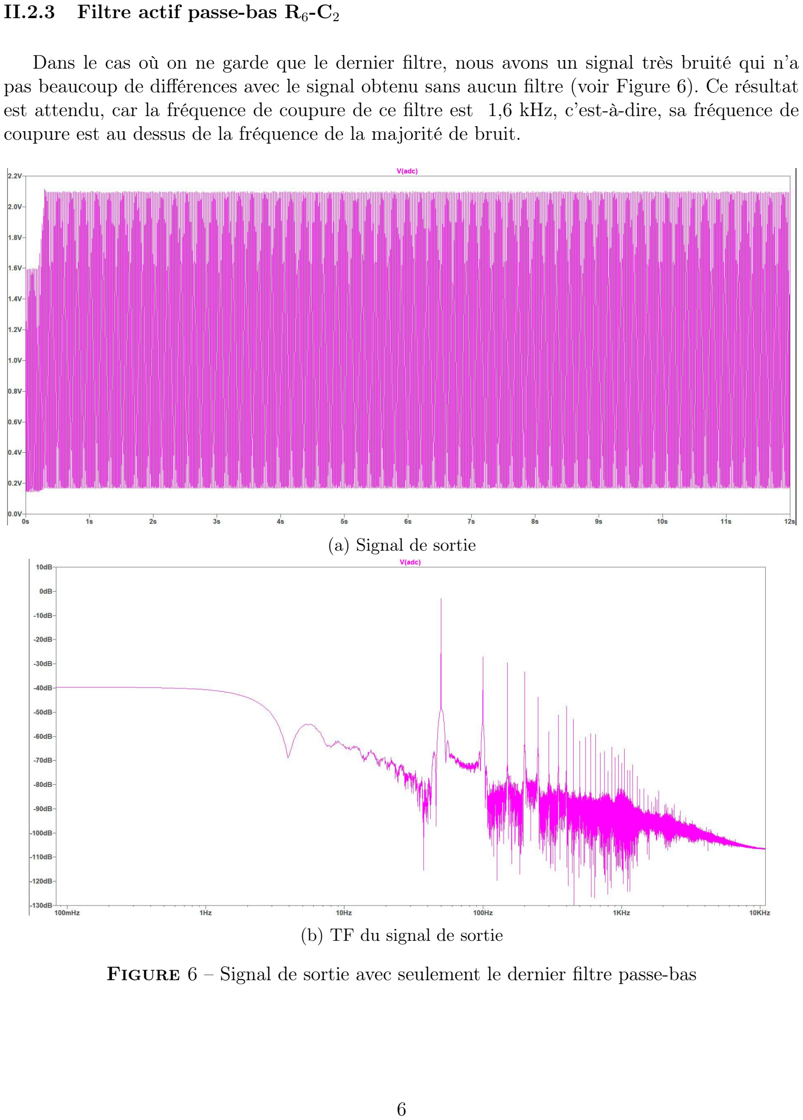
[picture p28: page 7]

II.2.3 Filtre actif passe-bas R6-C2

Dans le cas où on ne garde que le dernier filtre, nous avons un signal très bruité qui n’a pas beaucoup de différences avec le signal obtenu sans aucun filtre (voir Figure 6). Ce résultat est attendu, car la fréquence de coupure de ce filtre est 1,6 kHz, c’est-à-dire, sa fréquence de coupure est au dessus de la fréquence de la majorité de bruit.

(a) Signal de sortie
(b) TF du signal de sortie

Figure 6 – Signal de sortie avec seulement le dernier filtre passe-bas

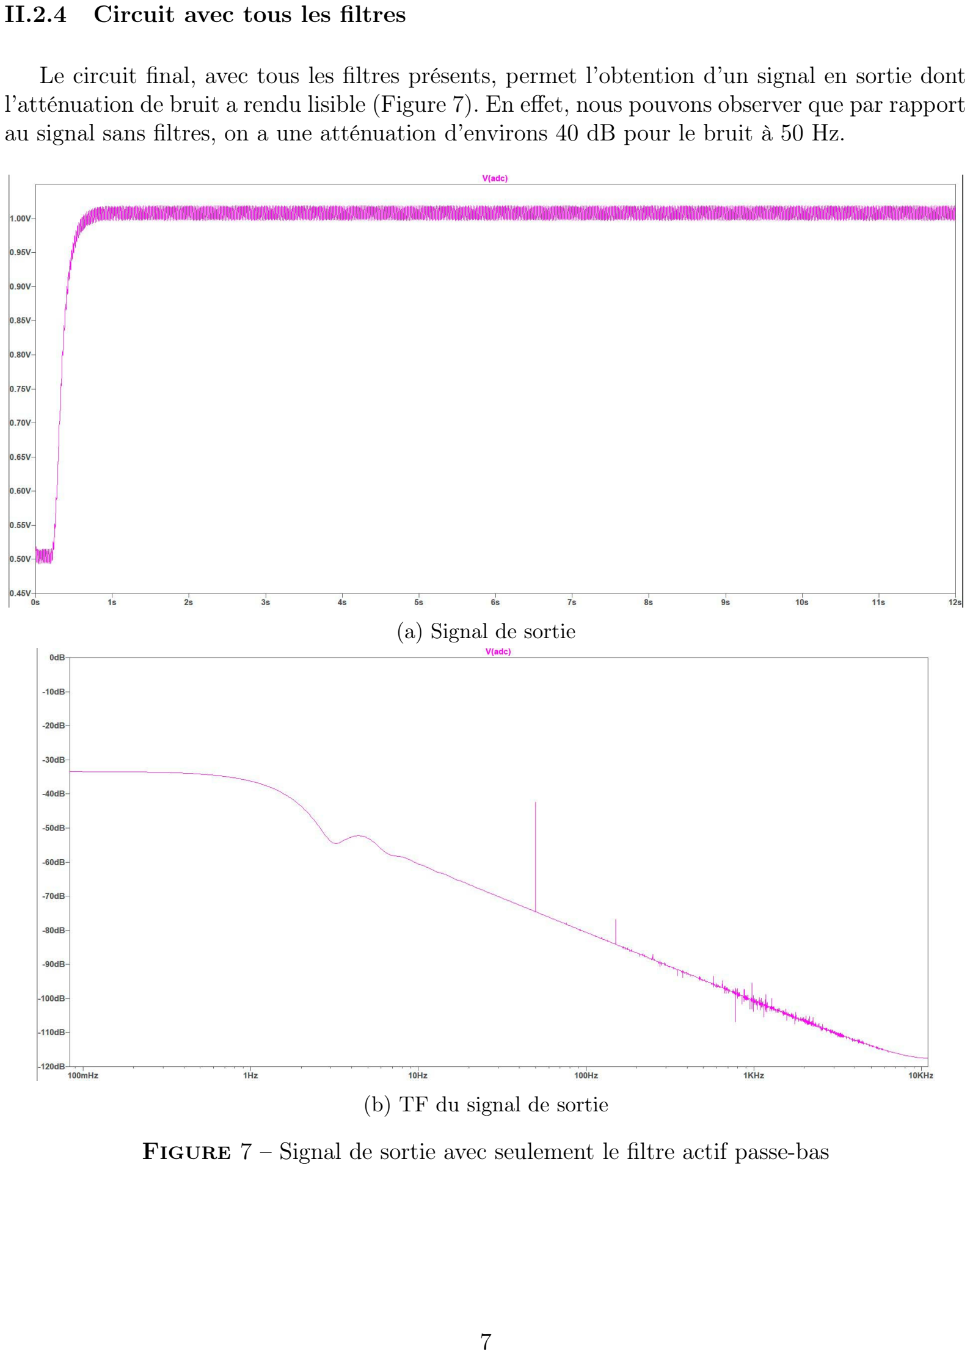
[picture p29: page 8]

II.2.4 Circuit avec tous les filtres

Le circuit final, avec tous les filtres présents, permet l’obtention d’un signal en sortie dont l’atténuation de bruit a rendu lisible (Figure 7). En effet, nous pouvons observer que par rapport au signal sans filtres, on a une atténuation d’environs 40 dB pour le bruit à 50 Hz.

(a) Signal de sortie
(b) TF du signal de sortie

Figure 7 – Signal de sortie avec seulement le filtre actif passe-bas

## III Calcul de la résistance du capteur

En appliquant les lois des mailles, nous avons pour l’entrée inverseuse un signal de sortie

VADC = (1 + R3
R2

)v

+ | (1)

et sur l’entrée non-inverseuse v

+ = Vcc

R1
R1 + R5 + Rs | (2)

(car c’est un pont diviseur). En injectant (2) dans (1), nous obtenons

VADC = (1 + R3
R2

)Vcc

R1
R1 + R5 + Rs

⇒

1
R1 + R5 + Rs

=

VADCR2
VccR1(R2 + R3)
⇒ | (3)

Rs =

VccR1(R2 + R3)

VADCR2

− R1 − R5 =

VccR1

VADC

(1 + R3
R2
) − R1 − R5 | (4)
IV | Conclusion

Le travail développé sur le logiciel LTSpice, nous a permis de mieux comprendre le choix des différent composants du circuit électrique qui accompagne le capteur papier. En effet, grâce aux successifs filtres placés, nous avons pu réduire de manière significative le bruit du signal de sortie, ce qui nous permet de connaître de manière précise la valeur de la résistance du capteur.

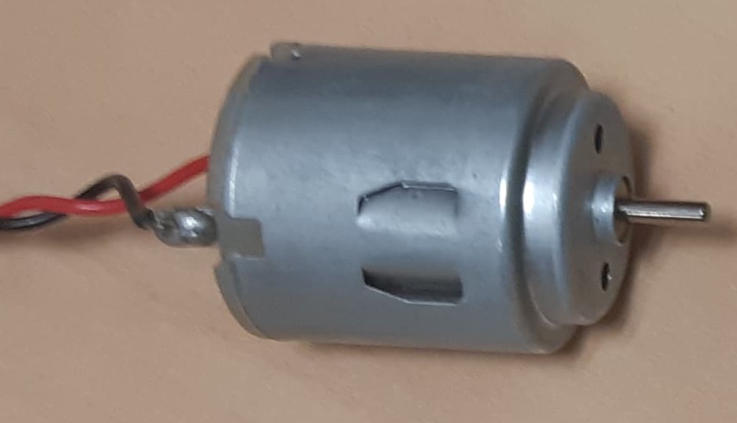
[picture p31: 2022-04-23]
Images/Rayon_de_courbure_04.jpg

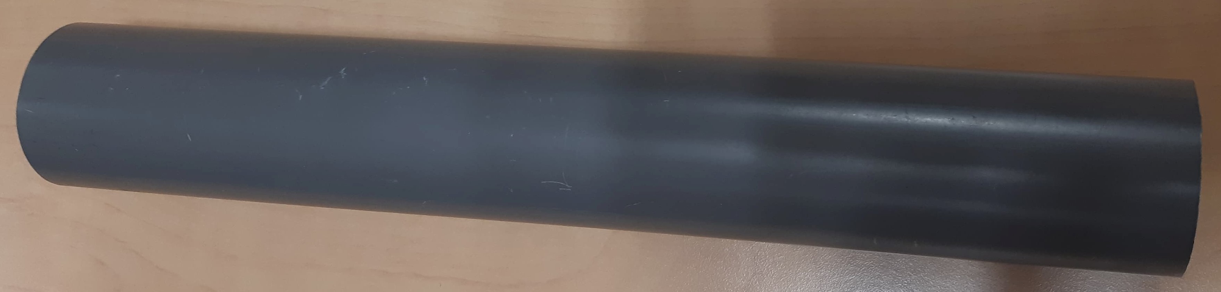
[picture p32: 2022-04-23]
Images/Rayon_de_courbure_03.jpg

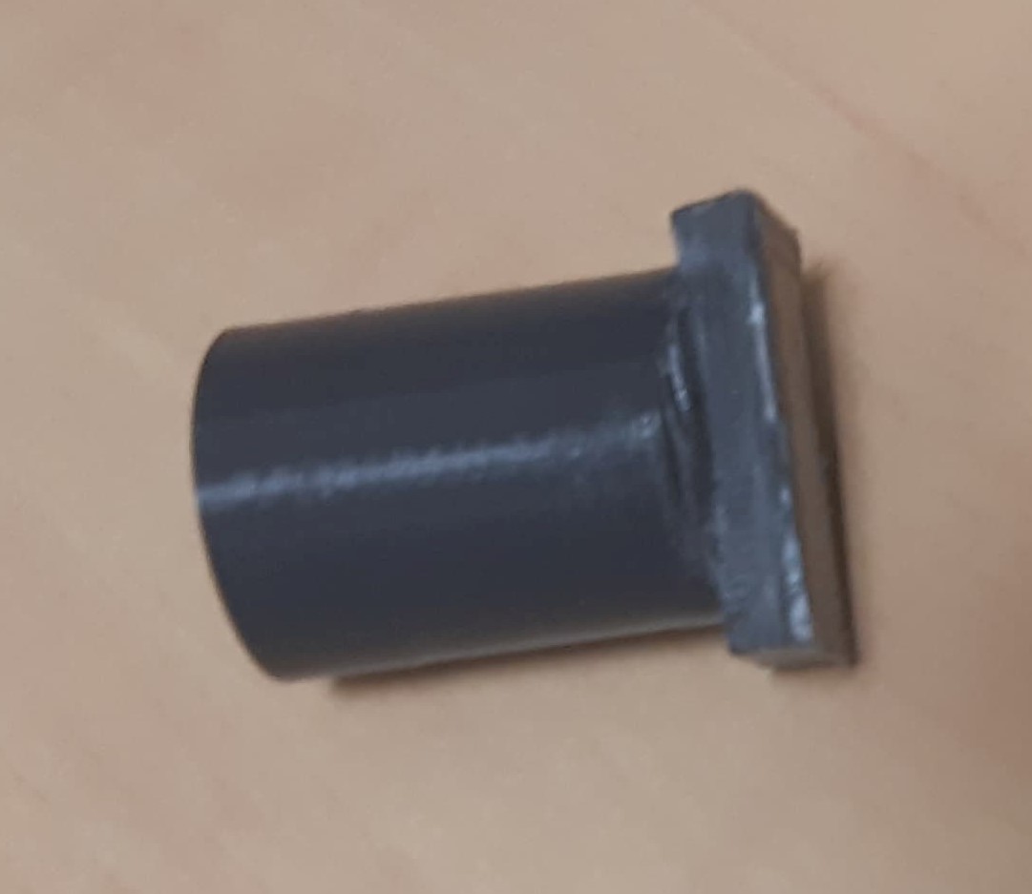
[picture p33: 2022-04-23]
Images/Rayon_de_courbure_05.jpg

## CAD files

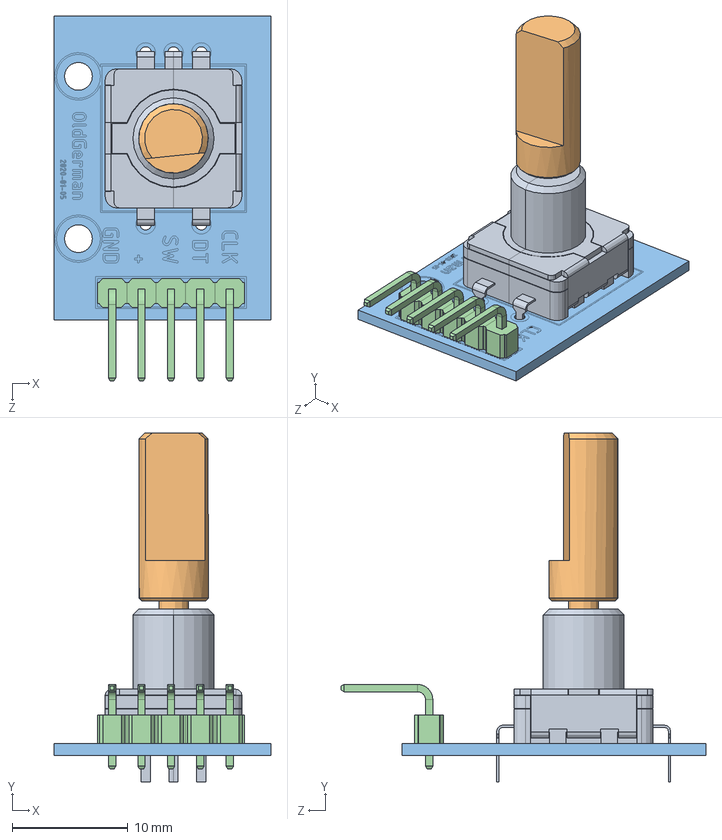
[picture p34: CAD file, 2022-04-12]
Shield PCB/Kicad_capteur_graphite/modele_3D-KY_040/sw2017 model/KY-040 Rotary Encoder.SLDASM
18.7 x 30.1 x 31.5 mm
Rotary Encoder
D-handle
pcb
2.54 5PIN 90

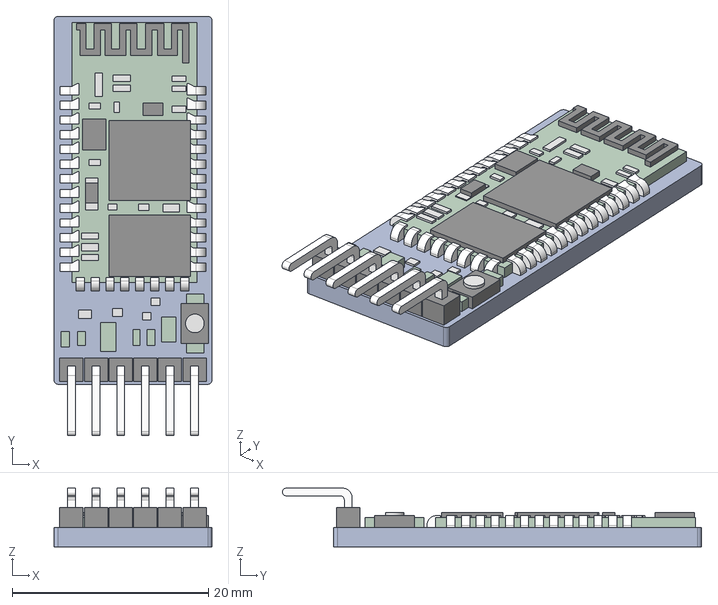
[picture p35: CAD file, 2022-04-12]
Shield PCB/Kicad_capteur_graphite/modele_3D-Bluetooth_HC-05/HC_05 Blue Tooth Module.stp
16.1 x 42.7 x 6.00 mm

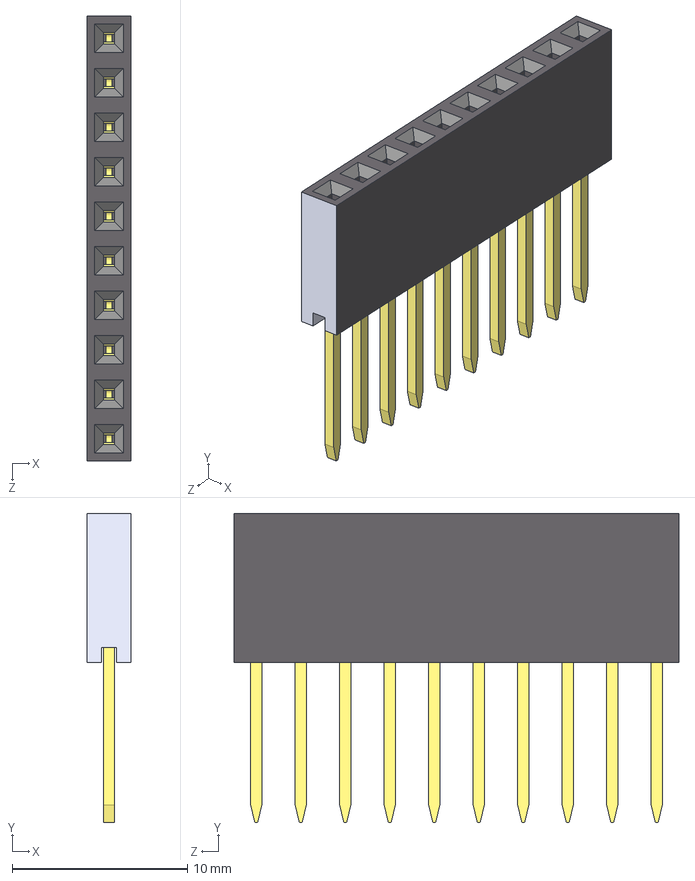
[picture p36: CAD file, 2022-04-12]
Shield PCB/Kicad_capteur_graphite/modele_3D-Header-female/1x10.STEP
2.54 x 17.6 x 25.4 mm

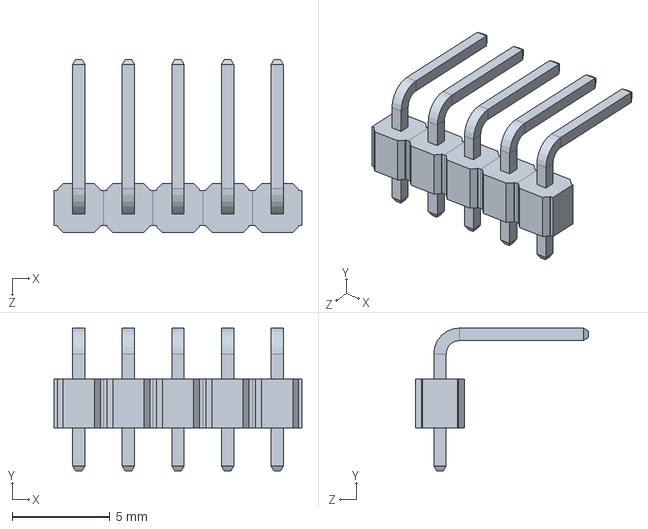
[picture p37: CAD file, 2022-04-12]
Shield PCB/Kicad_capteur_graphite/modele_3D-KY_040/sw2017 model/2.54 5PIN 90.SLDPRT
12.7 x 7.32 x 8.85 mm

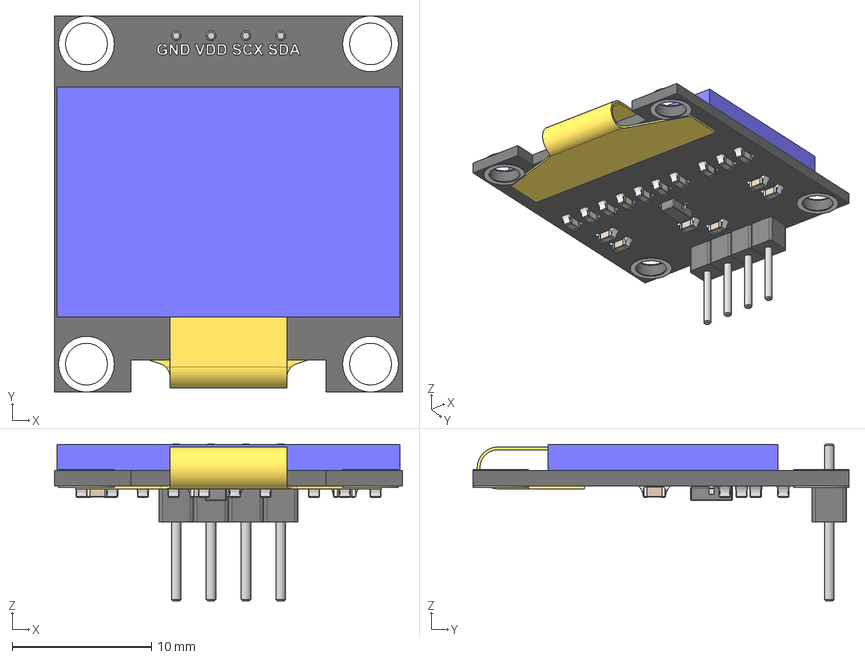
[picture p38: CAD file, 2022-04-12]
Shield PCB/Kicad_capteur_graphite/modele_3D-OLED_0.91/OLED display.step
25.0 x 27.0 x 11.2 mm
Hřebínek 4
cap0603_03 x 16
SOP-3

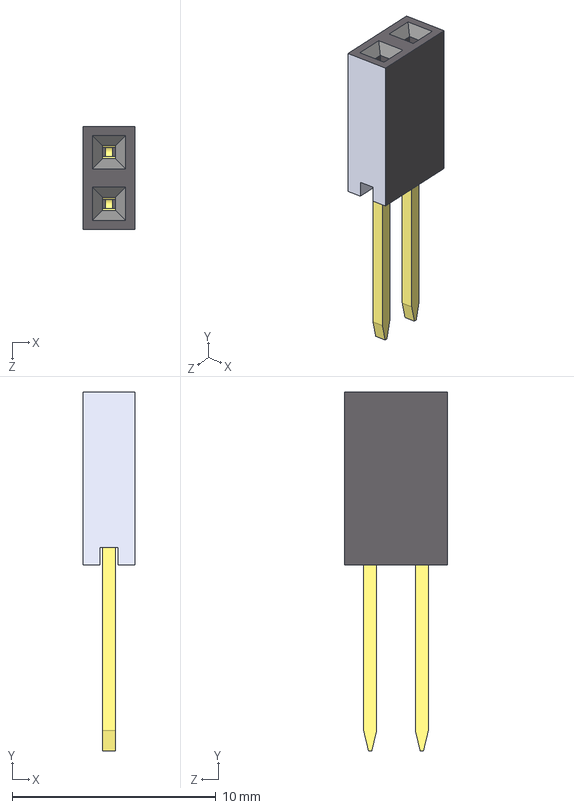
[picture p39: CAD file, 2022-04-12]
Shield PCB/Kicad_capteur_graphite/modele_3D-Header-female/1x2.STEP
2.54 x 17.6 x 5.08 mm

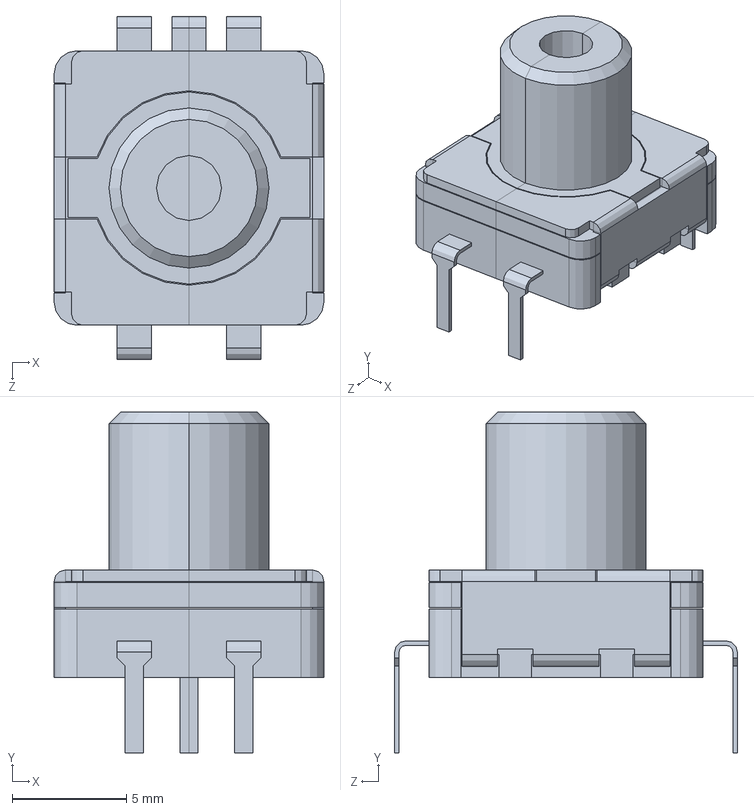
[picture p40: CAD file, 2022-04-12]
Shield PCB/Kicad_capteur_graphite/modele_3D-KY_040/sw2017 model/Rotary Encoder.SLDPRT
11.8 x 14.9 x 15.0 mm

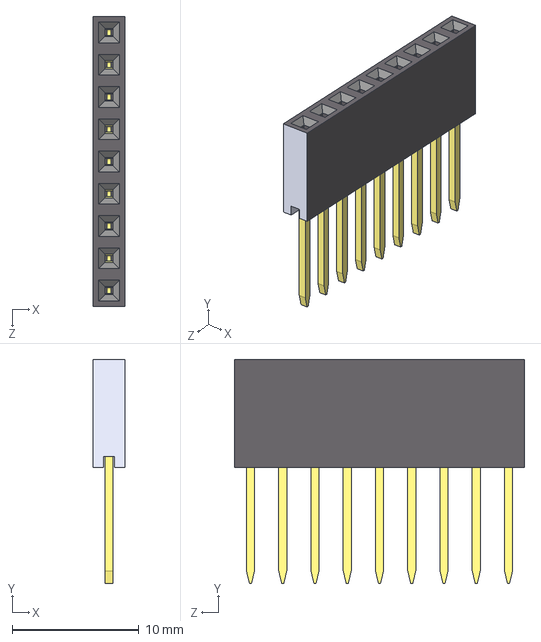
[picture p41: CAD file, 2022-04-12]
Shield PCB/Kicad_capteur_graphite/modele_3D-Header-female/1x9.STEP
2.54 x 17.6 x 22.9 mm

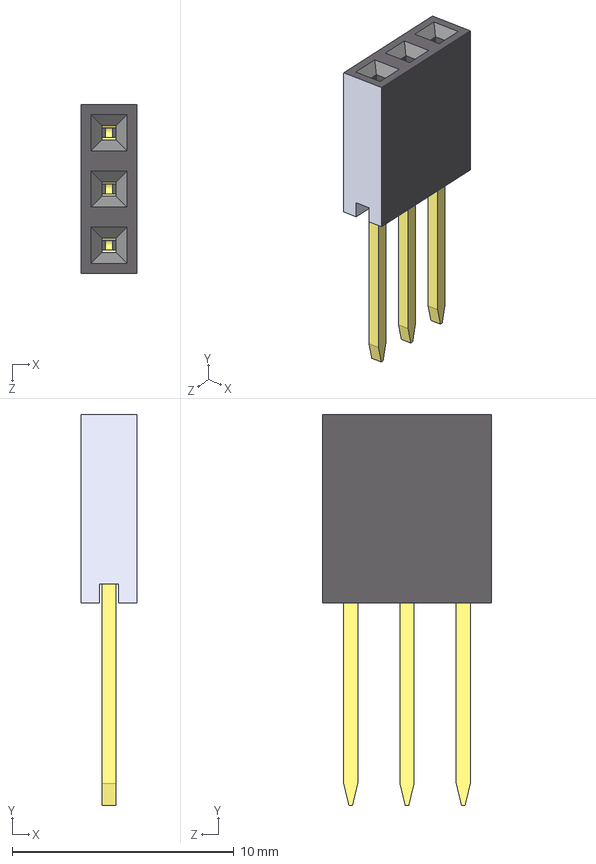
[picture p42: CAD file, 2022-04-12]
Shield PCB/Kicad_capteur_graphite/modele_3D-Header-female/pin header female 2.54mm_0.1in.STEP
2.54 x 17.6 x 7.62 mm

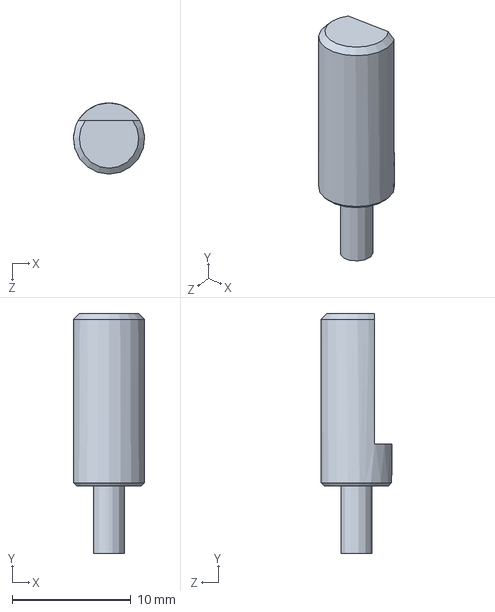
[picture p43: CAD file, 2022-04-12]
Shield PCB/Kicad_capteur_graphite/modele_3D-KY_040/sw2017 model/D-handle.SLDPRT
6.00 x 20.2 x 6.00 mm

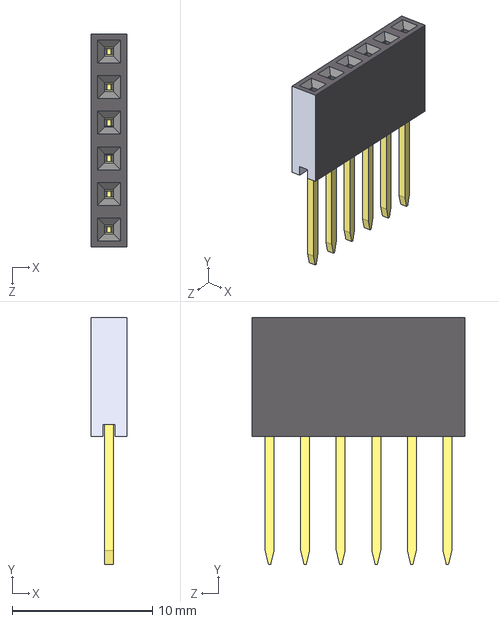
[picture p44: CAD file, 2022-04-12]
Shield PCB/Kicad_capteur_graphite/modele_3D-Header-female/1x6.STEP
2.54 x 17.6 x 15.2 mm

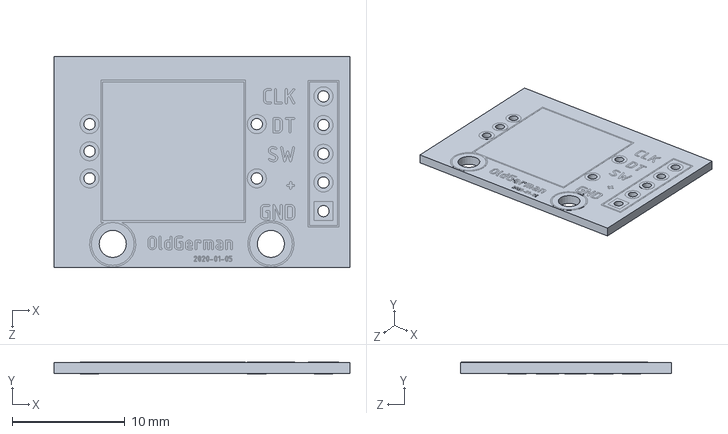
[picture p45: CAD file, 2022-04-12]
Shield PCB/Kicad_capteur_graphite/modele_3D-KY_040/sw2017 model/pcb.SLDPRT
26.2 x 1.02 x 18.7 mm

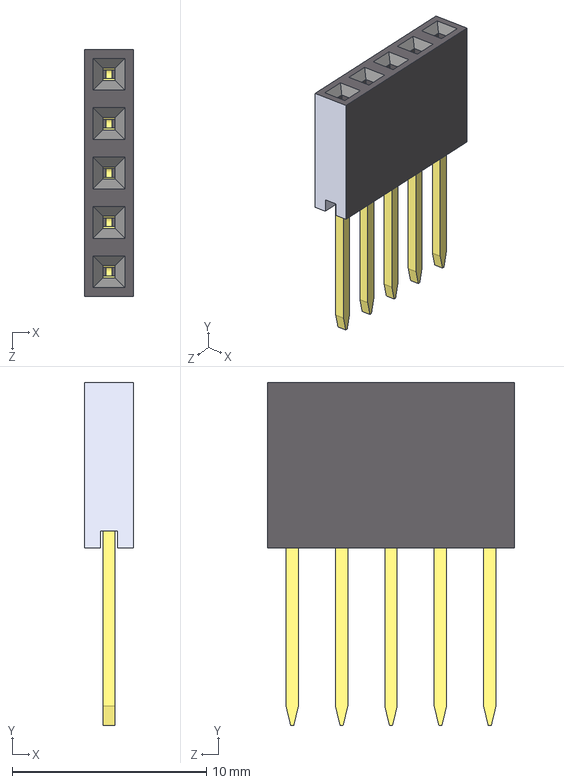
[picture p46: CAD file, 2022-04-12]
Shield PCB/Kicad_capteur_graphite/modele_3D-Header-female/1x5.STEP
2.54 x 17.6 x 12.7 mm

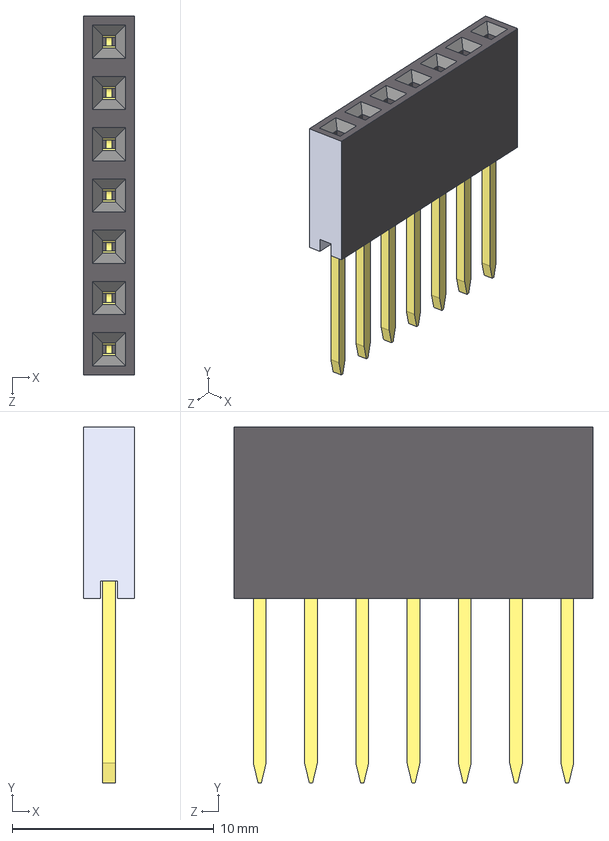
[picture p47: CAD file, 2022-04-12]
Shield PCB/Kicad_capteur_graphite/modele_3D-Header-female/1x7.STEP
2.54 x 17.6 x 17.8 mm

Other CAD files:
Shield PCB/Kicad_capteur_graphite/modele_3D-KY_040/KY-040 Rotary Encoder.STEP
Shield PCB/Kicad_capteur_graphite/modele_3D-Header-female/1x4.STEP
Shield PCB/Kicad_capteur_graphite/modele_3D-Bluetooth_HC-05/HC_05 Blue Tooth Module.ipt
Shield PCB/Kicad_capteur_graphite/modele_3D-Header-female/pin_header_female_2.54mm_0.1in.STEP

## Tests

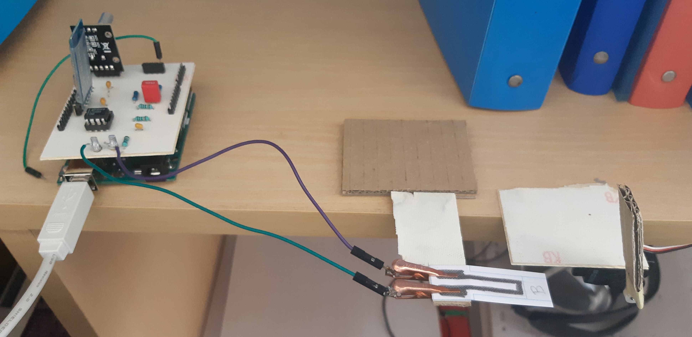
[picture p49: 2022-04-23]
Images/Test_Repetabilite_02.jpg

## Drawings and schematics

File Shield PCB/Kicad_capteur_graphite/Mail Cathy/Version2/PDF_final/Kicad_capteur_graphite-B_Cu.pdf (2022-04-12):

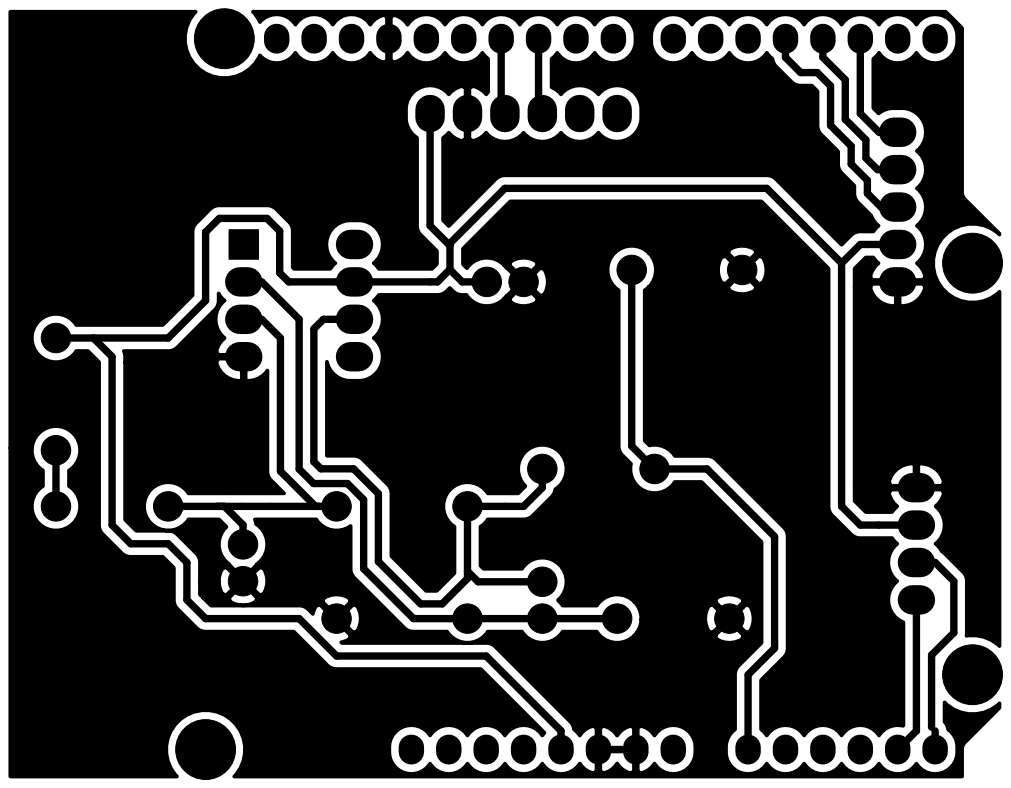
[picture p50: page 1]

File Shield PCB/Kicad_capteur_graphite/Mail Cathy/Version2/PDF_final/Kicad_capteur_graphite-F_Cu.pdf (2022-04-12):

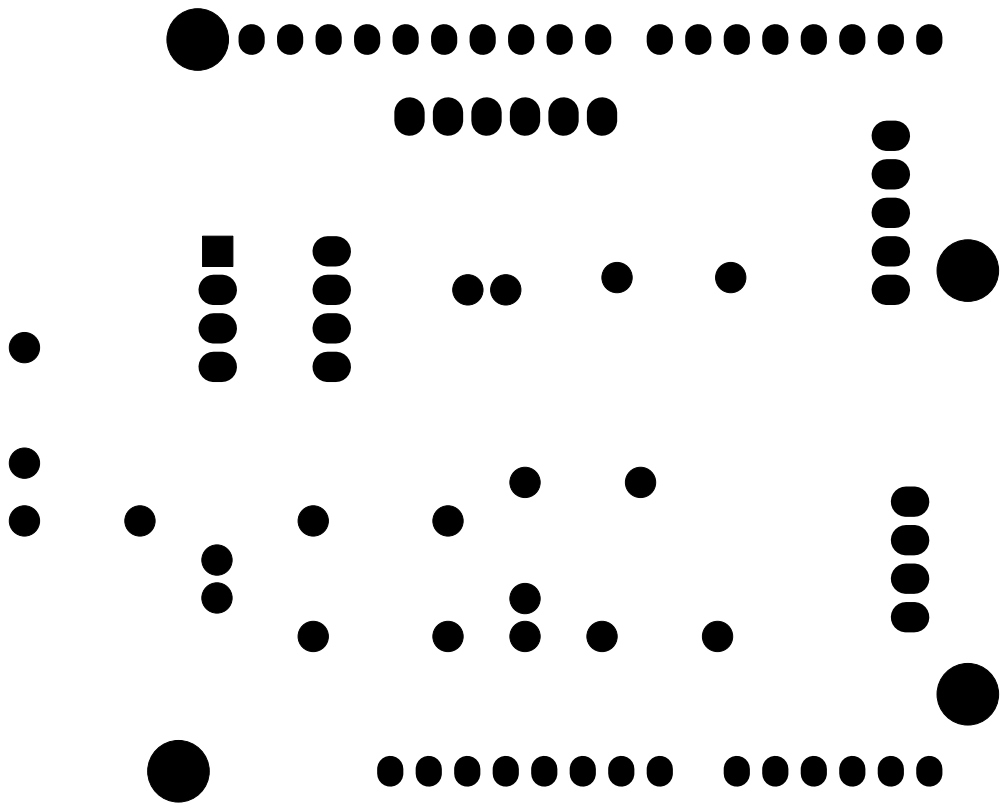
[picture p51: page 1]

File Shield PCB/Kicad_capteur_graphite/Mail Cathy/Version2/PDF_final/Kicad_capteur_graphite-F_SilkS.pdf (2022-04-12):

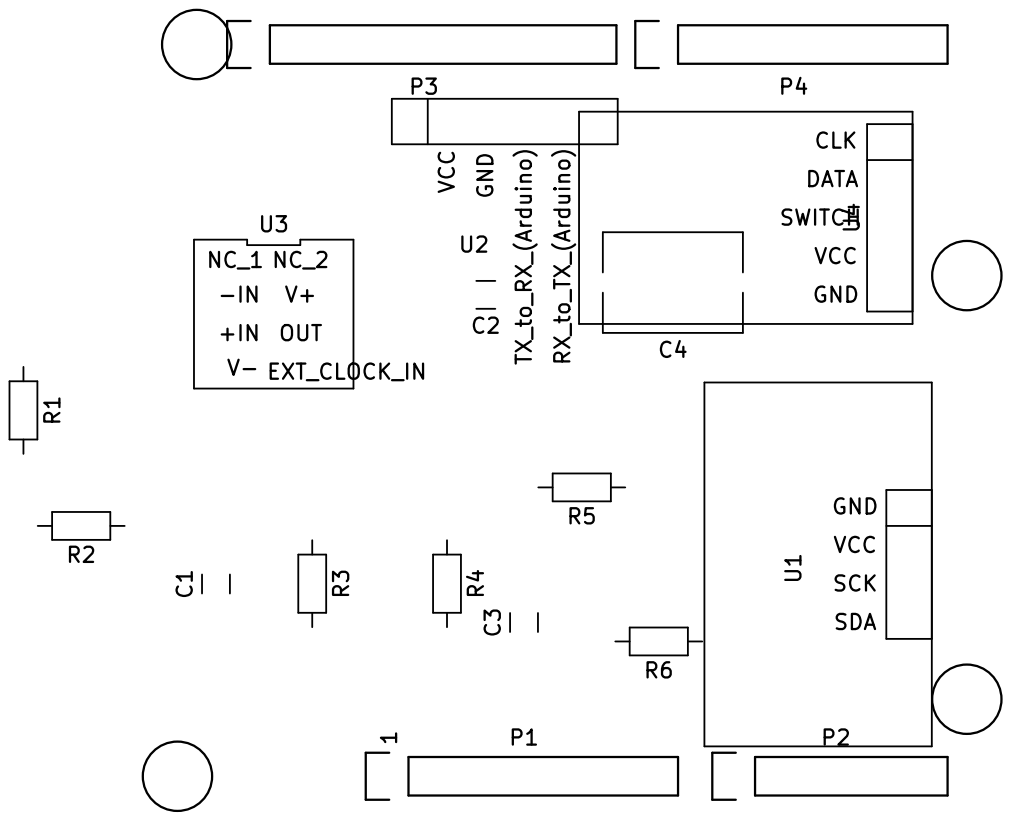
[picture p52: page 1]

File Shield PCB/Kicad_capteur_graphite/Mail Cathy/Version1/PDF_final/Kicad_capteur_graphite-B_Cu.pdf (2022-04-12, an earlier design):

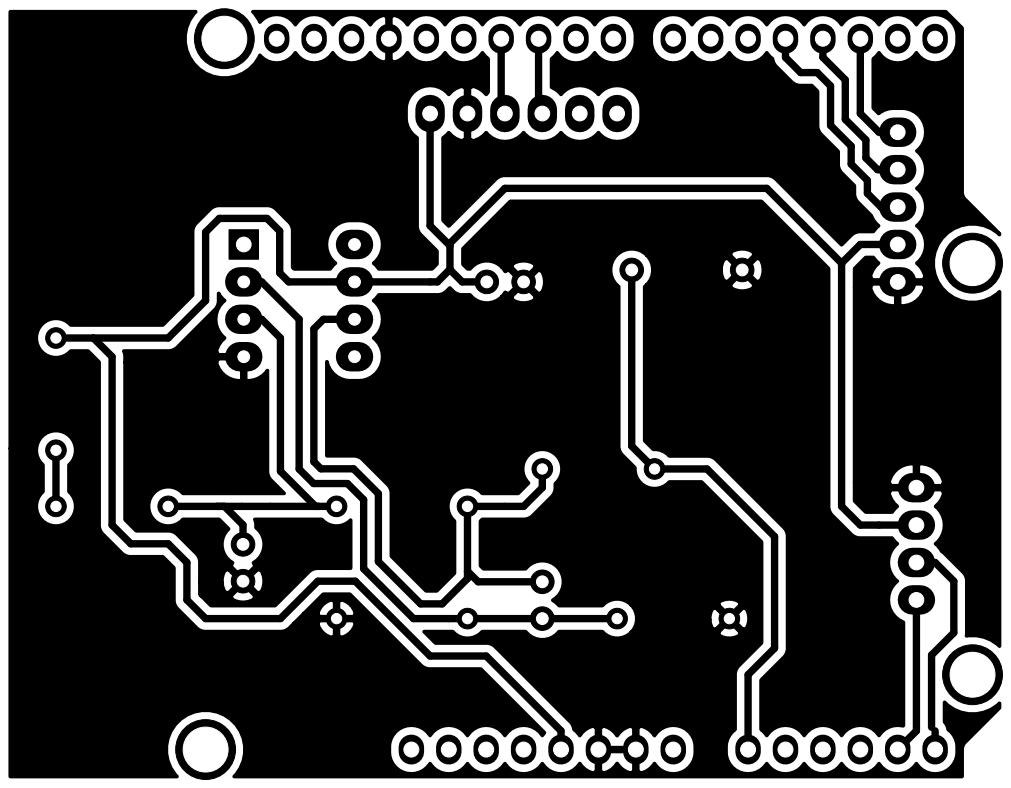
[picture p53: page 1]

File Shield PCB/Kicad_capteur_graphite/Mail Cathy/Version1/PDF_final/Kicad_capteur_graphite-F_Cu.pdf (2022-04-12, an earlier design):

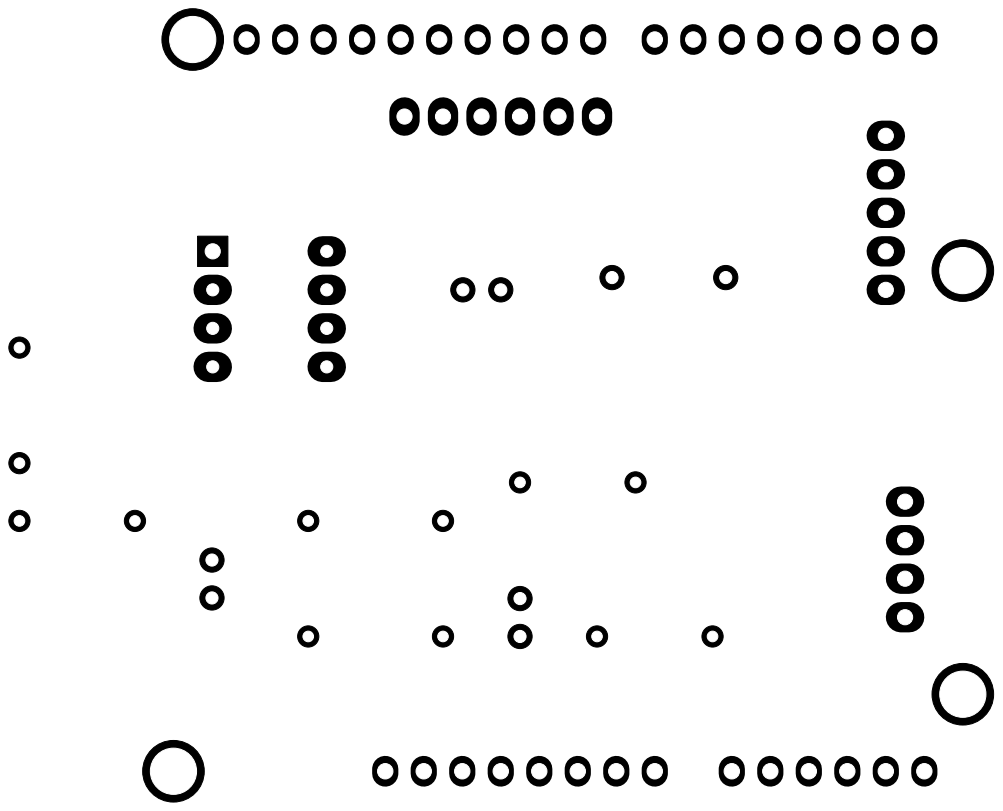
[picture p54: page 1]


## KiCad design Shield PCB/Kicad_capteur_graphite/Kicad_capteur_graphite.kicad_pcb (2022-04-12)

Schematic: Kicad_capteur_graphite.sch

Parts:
C1, C2, C3: 100n; C_Disc_D3.0mm_W1.6mm_P2.50mm
C4: 100n; C_Rect_L9.0mm_W6.4mm_P7.50mm_MKT
P1: Power; Socket_Strip_Arduino_1x08
P2: Analog; Socket_Strip_Arduino_1x06
P3: Digital; Socket_Strip_Arduino_1x10
P4: Digital; Socket_Strip_Arduino_1x08
P5, P6, P7, P8: CONN_01X01; Arduino_1pin
R1: Rsensor; R_Axial_DIN0204_L3.6mm_D1.6mm_P7.62mm_Horizontal
R2: 10k; R_Axial_DIN0204_L3.6mm_D1.6mm_P7.62mm_Horizontal
R3, R4: 100k; R_Axial_DIN0204_L3.6mm_D1.6mm_P7.62mm_Horizontal
R5, R6: 1k; R_Axial_DIN0204_L3.6mm_D1.6mm_P7.62mm_Horizontal
U1: OLED_0.91; OLED
U2: Bluetooth-HC05; BLUETOOTH_HC05
U3: LTC1050
U4: KY-040; KY_040

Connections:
+3V3: P1.4
+5V: C2.2, P1.5, R1.1, U1.2 (VCC), U2.1 (VCC), U3.7 (V+), U4.4 (VCC)
/0(Rx): P4.8
/1(Tx): P4.7
/5(**): P4.3
/6(**): P4.2
/7: P4.1
/8: P3.10
/9(**): P3.9
/12(MISO): P3.6
/13(SCK): P3.5
/A1: P2.2
/A2: P2.3
/A3: P2.4
/A4_SDA: P3.2
/A5_SCL: P3.1
/AREF: P3.3
/IOREF: P1.2
/Reset: P1.3
/Vin: P1.8
ADC: C4.2, P2.1, R5.1
CLK: P4.6, U4.1 (CLK)
DATA: P4.5, U4.2 (DATA)
GND: C1.1, C2.1, C4.1, P1.6, P1.7, P3.4, R3.2, R6.1, U1.1 (GND), U2.2 (GND), U3.4 (V-), U4.5 (GND)
IN+: C1.2, R2.1, R3.1, U3.3 (+IN)
IN-: C3.1, R4.2, R6.2, U3.2 (-IN)
unnamed: C3.2, R4.1, R5.2, U3.6 (OUT)
unnamed: R1.2, R2.2
RX: P3.7, U2.3 (TX_to_RX_(Arduino))
SCK: P2.6, U1.3 (SCK)
SDA: P2.5, U1.4 (SDA)
SWITCH: P4.4, U4.3 (SWITCH)
TX: P3.8, U2.4 (RX_to_TX_(Arduino))

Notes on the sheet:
Holes
Shield for Arduino that uses the same pin disposition like "Uno" board Rev 3.

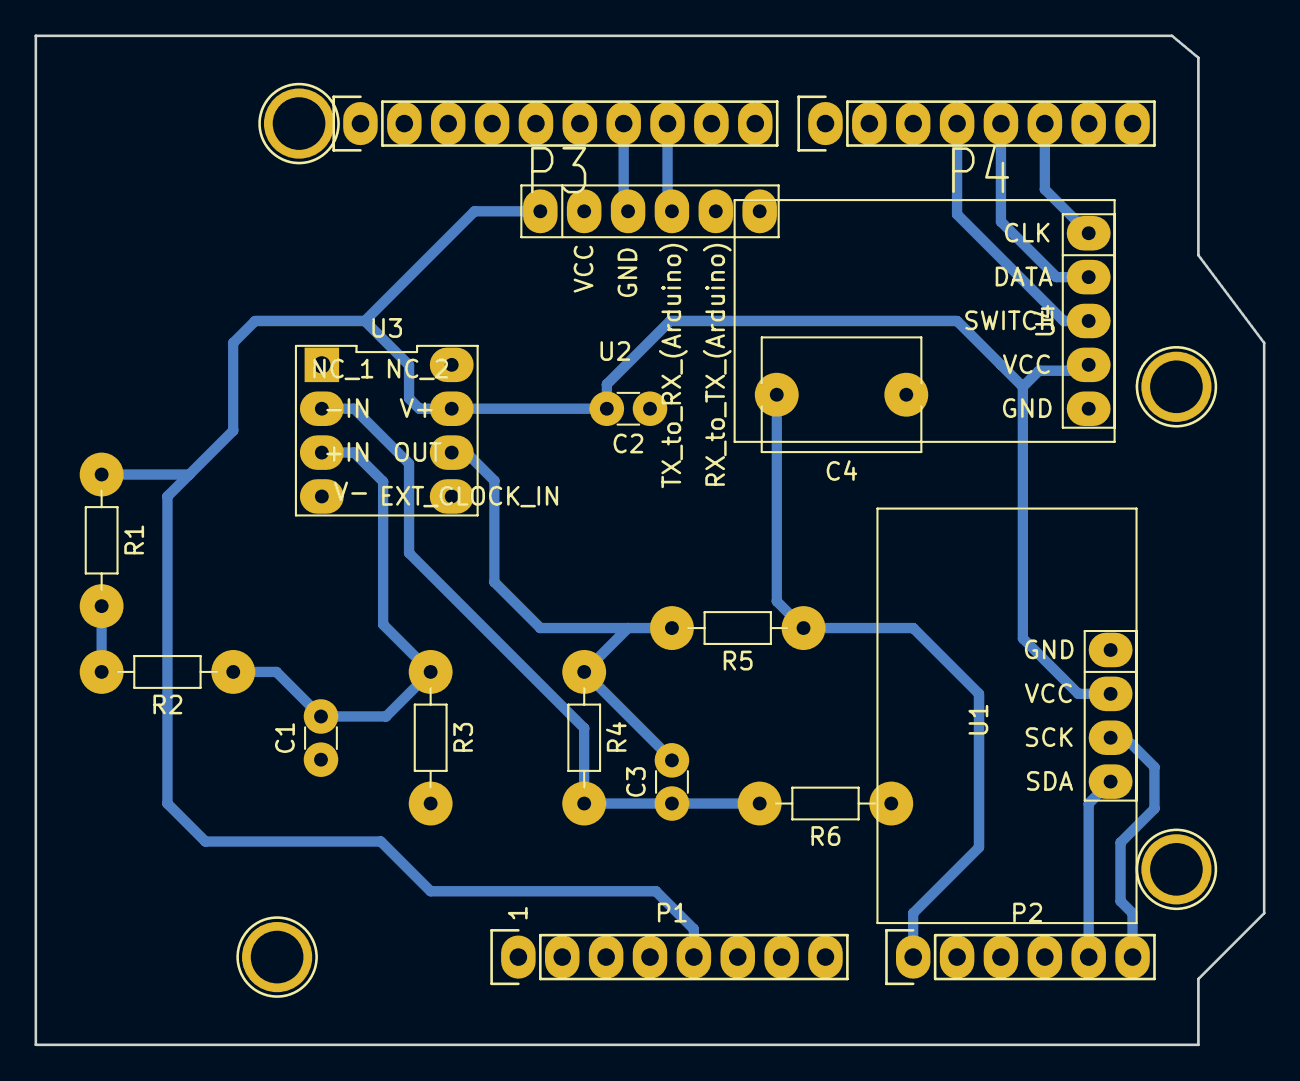
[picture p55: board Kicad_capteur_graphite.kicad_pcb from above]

Board: 2 copper layers, 71.1 x 58.4 mm, 22 parts (0 on the bottom side), 14 nets.

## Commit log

2022-04-12 AJOUT Kicad
    [1x10.STEP, 1x2.STEP, 1x4.STEP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]
2022-04-23 Shield PCB
    [1x10.STEP, 1x2.STEP, 1x4.STEP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]
2022-04-23 Banc de test
2022-04-23 rayon de courbure
2022-05-13 APK + Arduino
